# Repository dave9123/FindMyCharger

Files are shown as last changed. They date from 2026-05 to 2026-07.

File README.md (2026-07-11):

# FindMyCharger

<p align="center">
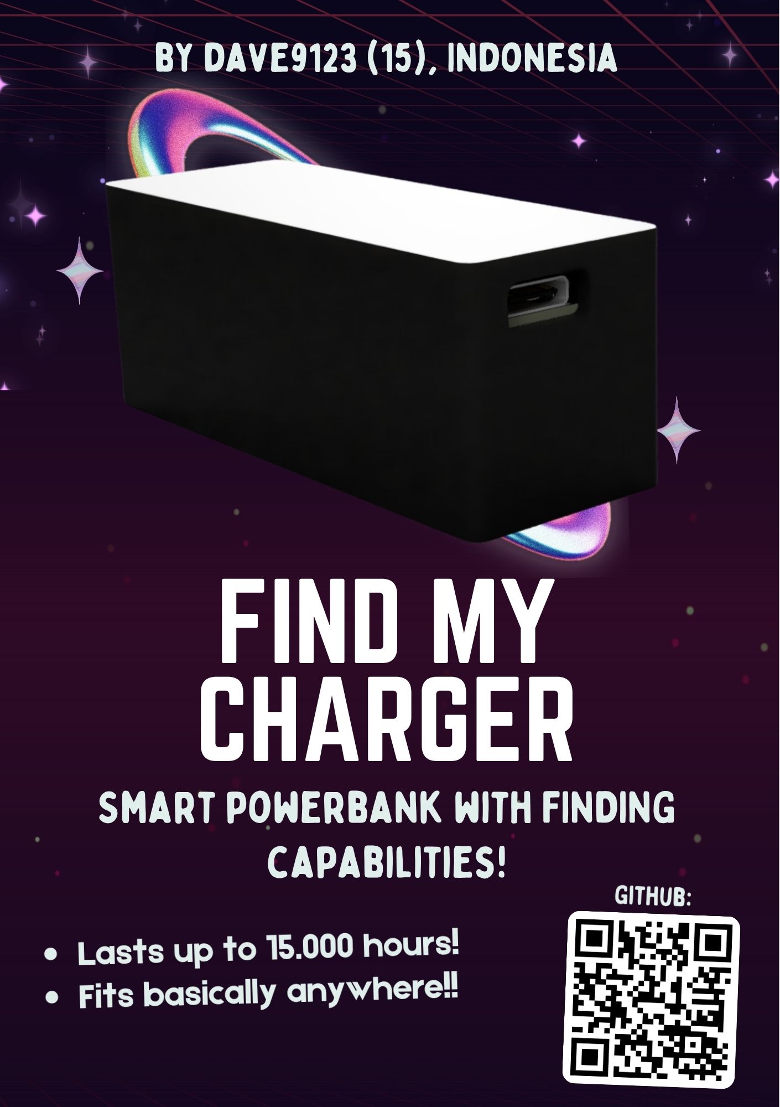
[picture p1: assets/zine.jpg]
	
	<br><a href="./zine.pdf">View Magazine</a> - <a href="#bom">View BOM</a>
</p>

FindMyCharger is a smart powerbank with finding capabilities so you don't have to worry where did you place your powerbank!

## Why?

I've been forgetting things a lot, also it can be part of aging (or ekhem ekhem sleep depreviation) which then causes people to lose their stuff. I don't hope for it, but there might be a chance that someone would steal your bag, and this just gives you a piece of mind!

## How it Works

IP5353 handles powerbank-like controls for charging and charging other devices, E104-BT5005A (based on nRF52805) transmits BLE packets which can be used with [Apple's FindMy](https://github.com/dchristl/macless-haystack) and/or [Google's Find Hub](https://github.com/leonboe1/GoogleFindMyTools).

## Build Instructions

You can either:
- PCBA
- Manual Solder 

Afterwards, you'll need:

1. Everything from [BOM](./BOM.md) (pick PCBA/detailed depending on your usecase)
2. SWD Debugging Interface
3. 4x Jumper Wires

(additional if manual solder)

4. Soldering Iron
5. Solder

Steps:
1. Print the PCB from [pcb/jlcpcb/production_files/GERBER-FindMyCharger.zip](./pcb/jlcpcb/production_files/GERBER-FindMyCharger.zip)
2. Solder the components based on [BOM](#BOM) or PCBA with [JLCPCB CPL](./pcb/jlcpcb/production_files/CPL-FindMyCharger.csv) and [JLCPCB BOM](./pcb/jlcpcb/production_files/BOM-FindMyCharger.csv)
3. 3D print the casing in [CAD folder](./cad/components/)
4. Place the battery on the bottom holder

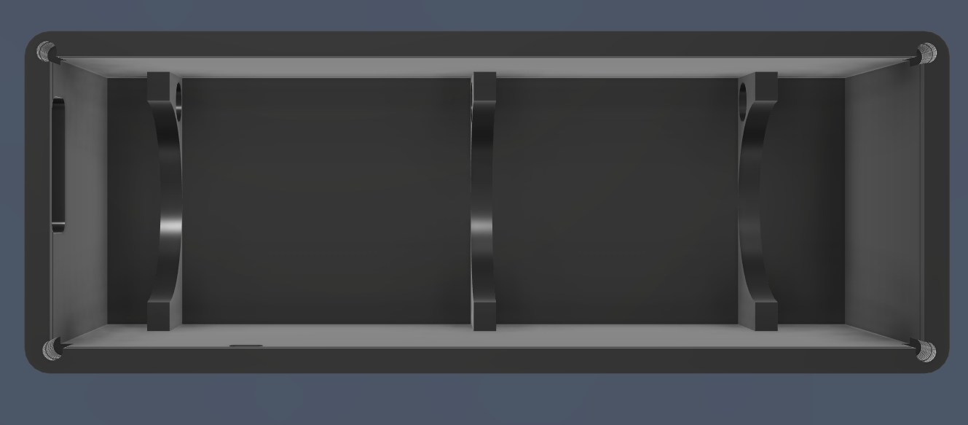
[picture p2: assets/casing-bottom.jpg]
Bottom Casing
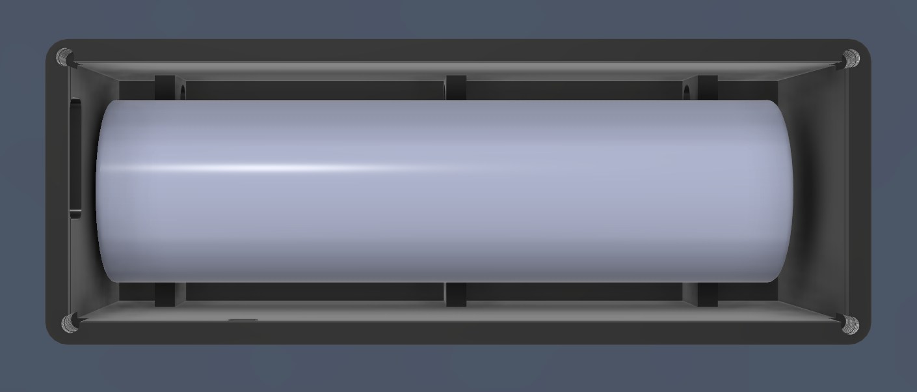
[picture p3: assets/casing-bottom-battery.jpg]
Bottom Casing with Battery
|  |  |
| :---: | :---: |

5. Solder battery with wires (to be soldered on the PCB)
6. Place the bottom holder dock

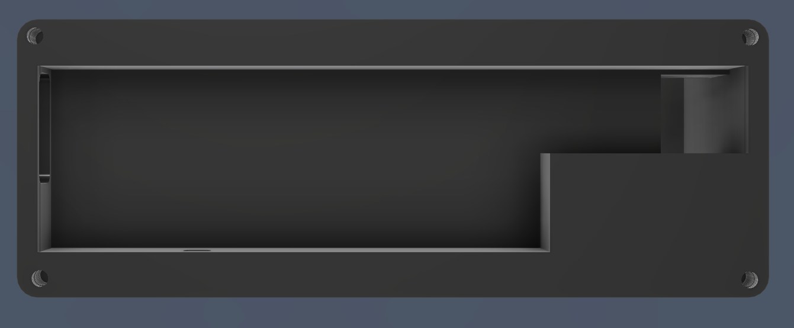
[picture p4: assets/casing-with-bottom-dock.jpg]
Casing with Bottom Holder Dock
| Bottom Casing with Battery |  |
| :---: | :---: |

7. Place and fit the PCB on the dock

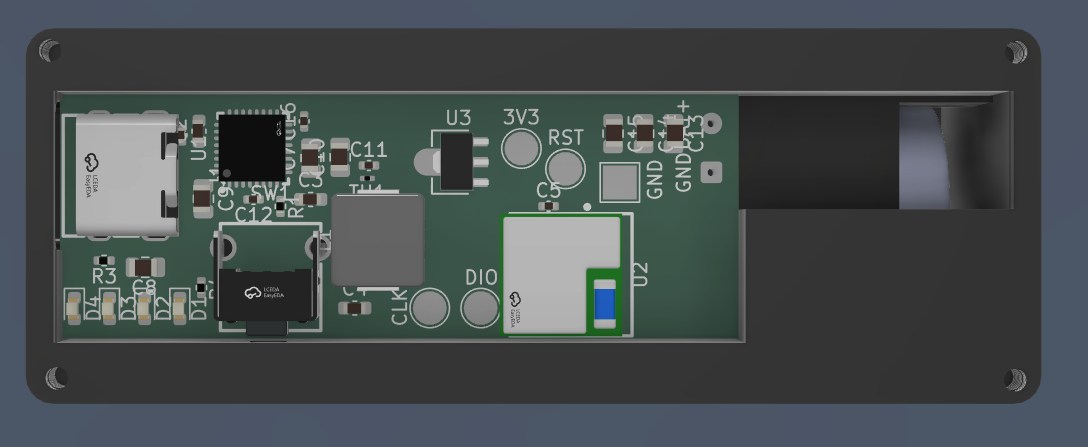
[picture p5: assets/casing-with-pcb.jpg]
Casing with PCB on the dock
| Casing with Bottom Holder Dock |  |
| :---: | :---: |

8. Build and flash the [firmware](#firmware) by connecting a SWD debugger to (SW)DIO, (SW)CLK, and GND
9. Place the top and screw it with M2x6

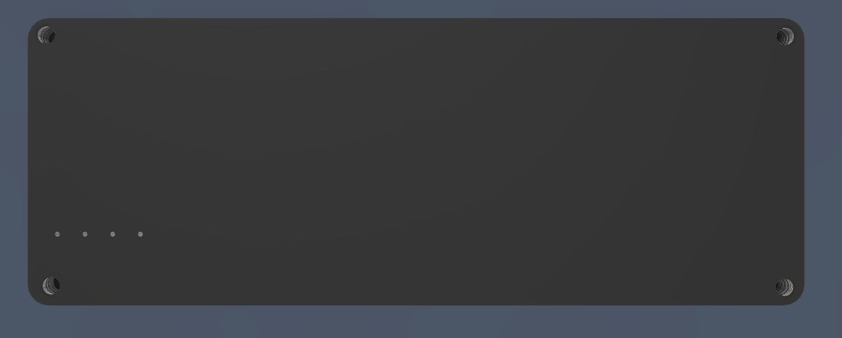
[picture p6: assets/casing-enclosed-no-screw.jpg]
Casing with Top
| Casing with PCB on the dock |  |
| --- | --- |

## Firmware

The firmware for FindMyCharger is using [Macless Haystack](https://github.com/dchristl/macless-haystack), a framework for custom FindMy network without having to own a Mac.

Macless Haystack is included in this repository as a submodule under [firmware/macless-haystack](../firmware/macless-haystack/)

### Prerequisites (guide below to install):

1. nRF Connect SDK
2. https://github.com/dchristl/macless-haystack repo or current (follow guide below)
3. Python 2/3 (with pip), download [here](https://www.python.org/downloads/)
4. Pip package ["cryptography"](http://pypi.org/project/cryptography) -- `pip install cryptography`
5. Visual Studio Code, download [here](https://code.visualstudio.com/)
6. CMake, download [here](https://cmake.org/download/) or `sudo apt install cmake`

 ### Clone repository along with submodules:

7. Install the ["nRF Connect for VS Code" VSCode Extension here](https://marketplace.visualstudio.com/items?itemName=nordic-semiconductor.nrf-connect)

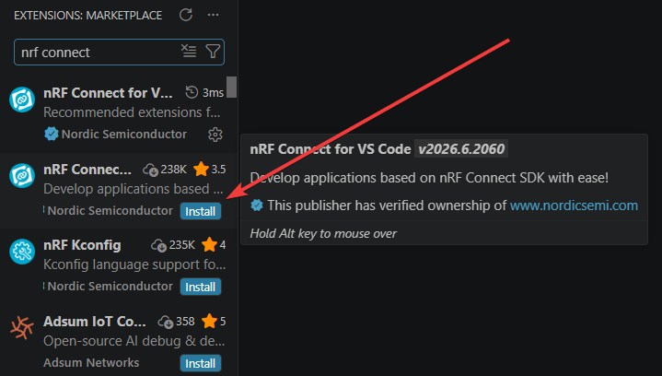
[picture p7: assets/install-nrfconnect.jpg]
Search for "nRF Connect for VS Code" and click Install


2. Open the nRF Connect extension on the left bar

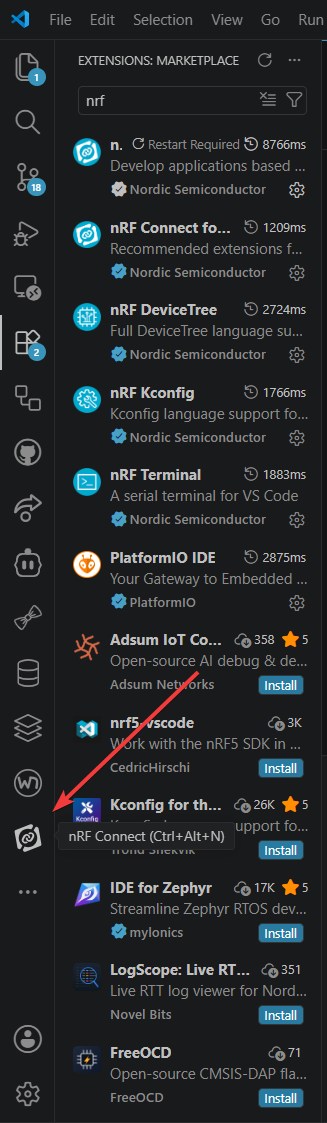
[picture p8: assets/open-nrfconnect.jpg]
Click on the chain with rectangles logo (nRF Connect extension)


3. Click on "Install SDK" and pick the latest version
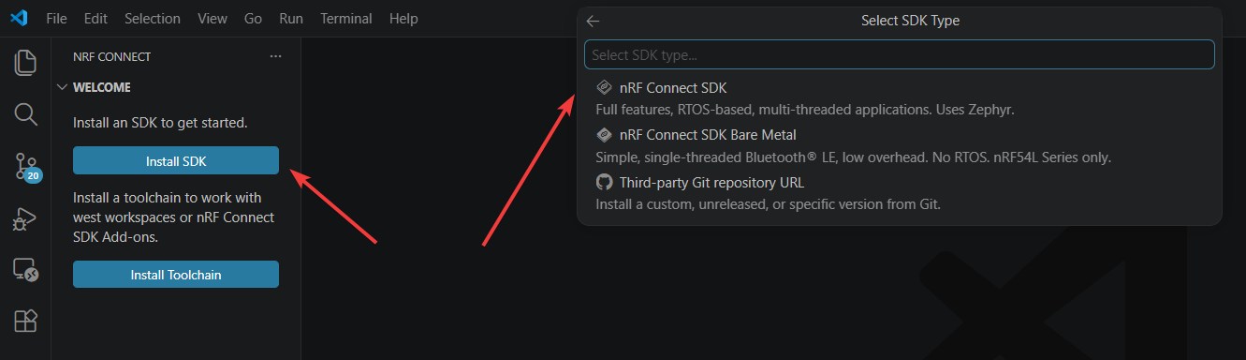
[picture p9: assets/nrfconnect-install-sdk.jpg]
Selecting "nRF Connect SDK" on SDK installation with nRF Connect for VS Code extension


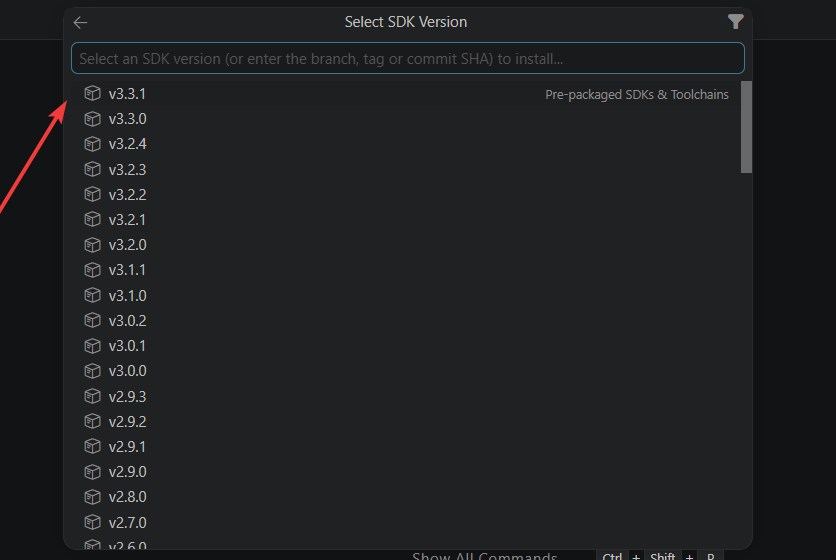
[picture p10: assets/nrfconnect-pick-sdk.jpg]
Picking the SDK version on nRF Connect

4. Click on "Install Toolchain" and pick the latest version

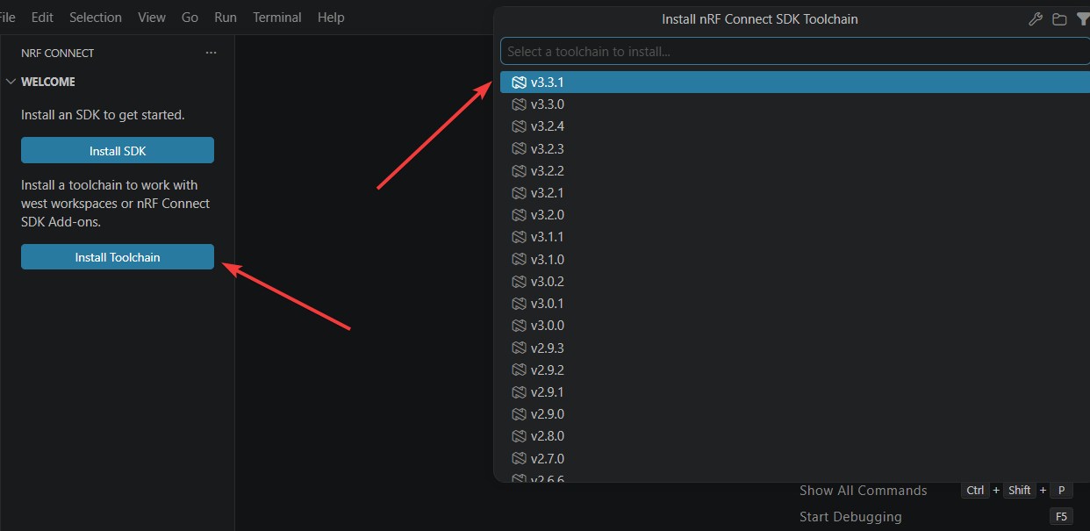
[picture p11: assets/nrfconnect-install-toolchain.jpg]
Clicking on "Install Toolchain" and picking the latest version


5. Wait for it to finish installing

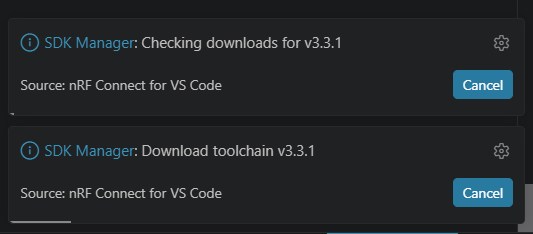
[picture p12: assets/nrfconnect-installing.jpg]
Installing progress notification


### Clone repository along with submodules

```
git clone --recurse-submodules https://github.com/dave9123/FindMyCharger

cd FindMyCharger/firmware/macless-haystack

git -C macless-haystack submodule update --init --remote --recursive
```

Then, you'll need to download the firmware (nrf52_firmware.bin) at Macless Haystack releases [here](https://github.com/dchristl/macless-haystack/releases) or build your own:
```
cd firmware/macless-haystack

py generate_keys.py # Note the output folder from the output "Output will be written to {OUTPUT_FOLDER}"

cd firmware/nrf5x

NRF_MODEL=nrf52 BOARD=BOARD_E104BT5032A make build

make patch
```

### Afterwards, update the finding public key

note: use Git Bash on Windows
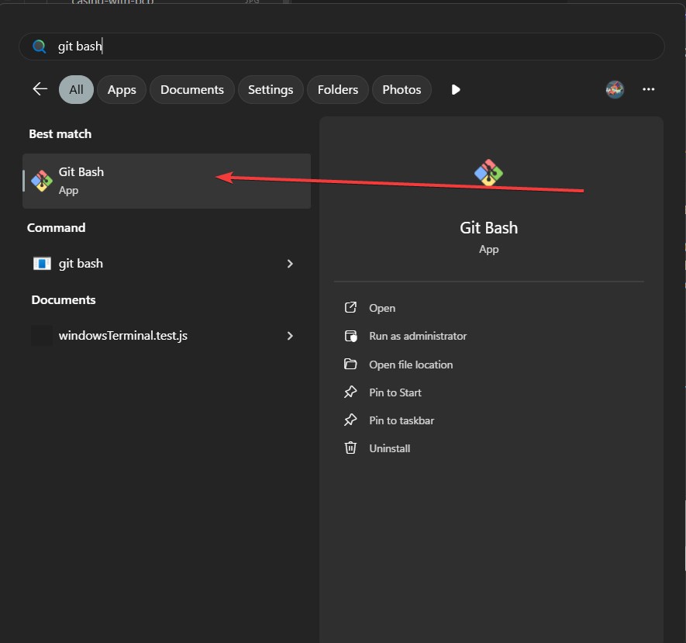
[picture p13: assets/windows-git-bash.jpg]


Replace "PREFIX_keyfile" with the path to your generated public key (stored in the ../../output folder)

```
export LC_CTYPE=C

xxd -p -c 100000 PREFIX_keyfile | xxd -r -p | dd of=nrf52_firmware.bin skip=1 bs=1 seek=$(grep -oba OFFLINEFINDINGPUBLICKEYHERE! nrf52_firmware.bin | cut -d ':' -f 1) conv=notrunc
```

### Patch and deploy firmware

```
openocd -f interface/stlink.cfg -c "transport select hla_swd" -f target/nrf52.cfg -c "init; halt; nrf5 mass_erase; program nrf52_firmware.bin verify; reset run; exit"
```

The complete guide on setting Macless Haystack can be found [here](https://github.com/dchristl/macless-haystackhttps://github.com/dchristl/macless-haystack)!

## Casing

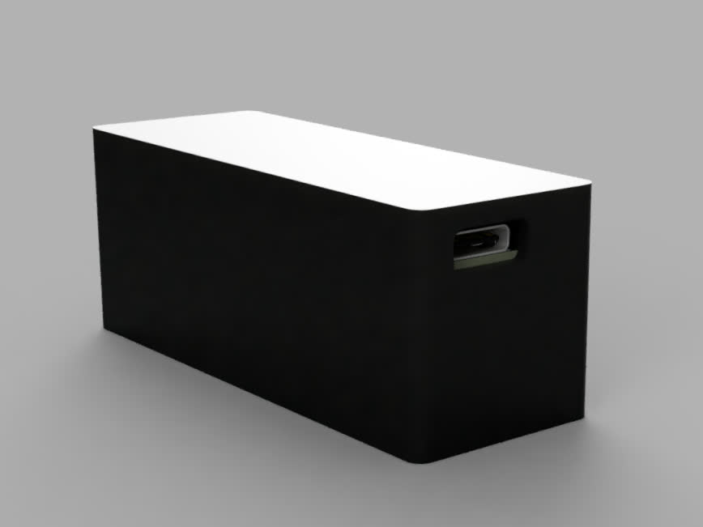
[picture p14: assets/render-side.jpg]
Side View
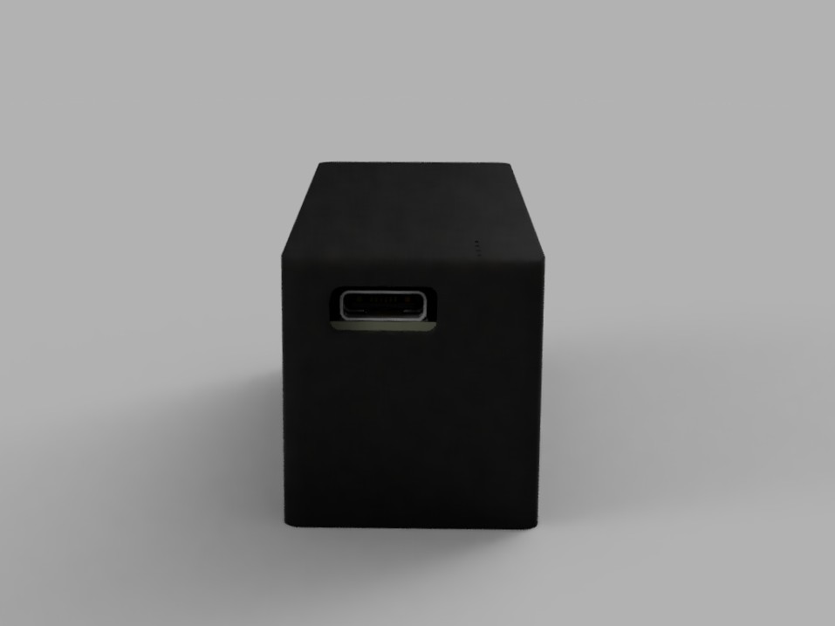
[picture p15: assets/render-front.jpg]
Front View
|  |  |
| :---: | :---: |

I'm honestly really proud of how it ends up, especially the sliding mechanism which makes everything easier to place

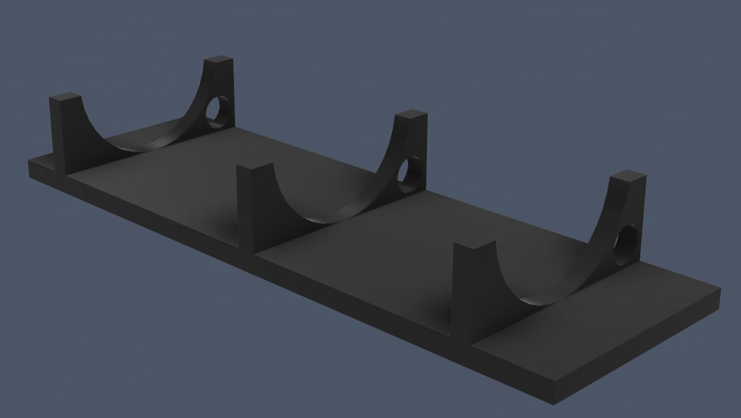
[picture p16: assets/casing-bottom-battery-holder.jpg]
Bottom Battery Holder
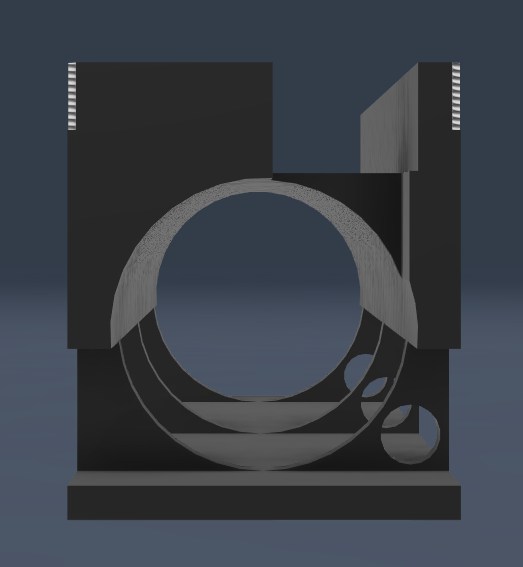
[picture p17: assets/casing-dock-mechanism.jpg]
Docking Mechanism
|  |  |
| :---: | :---: |

The holes on the side is for the cable to passthrough either the GND or positive side of the battery to be soldered onto the PCB

## Schematics

Detailed components list used can be found in the [BOM section](#bom)

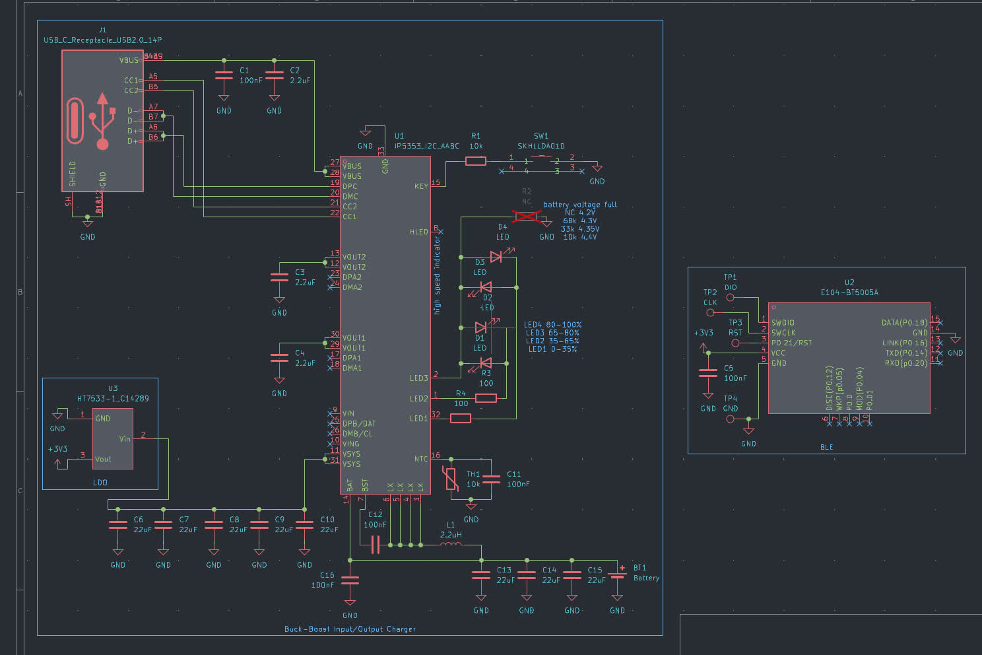
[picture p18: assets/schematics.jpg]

[View PDF](./assets/schematics.pdf)

## PCB

| Design | Rendered |
| :---: | :---: |
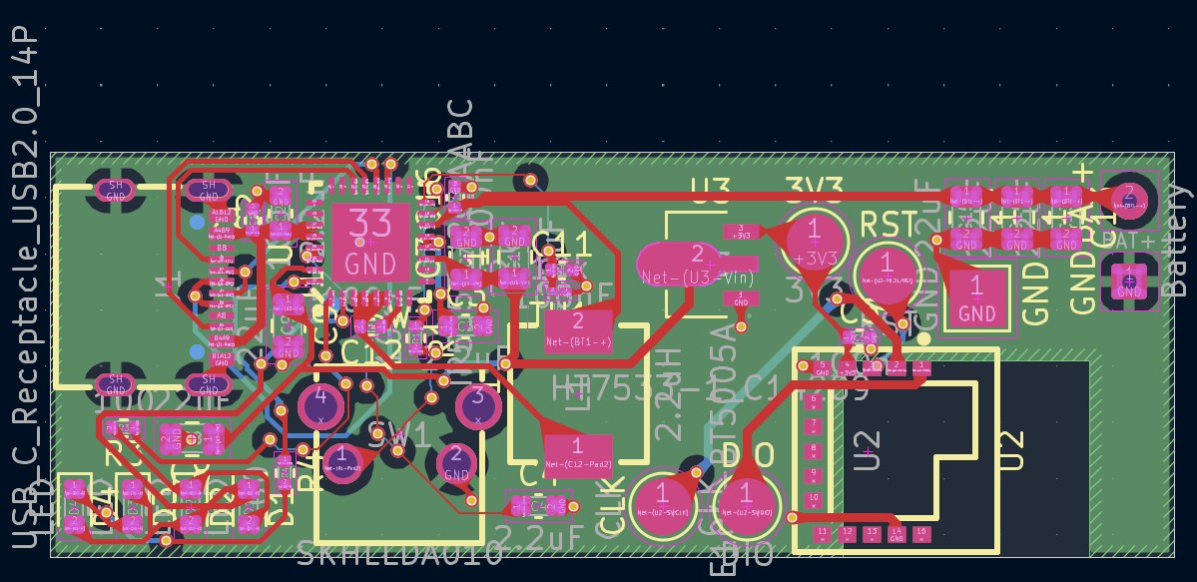
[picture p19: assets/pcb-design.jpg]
PCB Layout Design
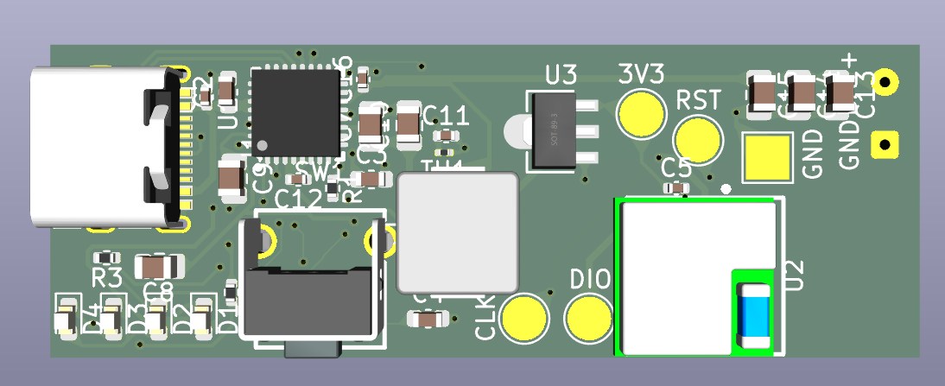
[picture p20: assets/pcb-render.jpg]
Rendered PCB
|  |  |

[View PDF](./assets/pcb.pdf)

Footprints used:
1. Battery Solder Pad - `Connector_Wire:SolderWire-0.1sqmm_1x02_P3.6mm_D0.4mm_OD1mm`
2. Capacitor 100nF - `Capacitor_SMD:C_0402_1005Metric`
3. Capacitor 2.2uF - `Capacitor_SMD:C_0603_1608Metric`
4. Capacitor 22uF - `Capacitor_SMD:C_0805_2012Metric`
5. LED `LED_SMD:LED_0603_1608Metric`
6. USB C Receptacle - `footprints:USB-C-SMD_TYPE-C16PIN` (imported from EasyEDA, included under `pcb/libraries/footprints.pretty)
7. Inductor 2.2uH - `footprints:IND-SMD_L6.0-W6.0_CHILISIN_HPPC06030` (imported from EasyEDA, included under `pcb/libraries/footprints.pretty`)
8. Resistor 10kΩ - `Resistor_SMD:R_0402_1005Metric`
9. Resistor 100Ω - `Resistor_SMD:R_0402_1005Metric`
10. 90deg Tactile Button - `footprints:KEY-TH_SKHLLDA010` (imported from EasyEDA, included under `pcb/libraries/footprints.pretty`)
11. Test Points - `TestPoint:TestPoint_Pad_D2.5mm`
12. IP5353 (charging) - `footprints:QFN-32_L5.0-W5.0-P0.50-TL-EP3.5` (imported from EasyEDA, included under `pcb/libraries/footprints.pretty`)
13. E104-BT5005A (BLE) - `footprints:BULETM-SMD_E104-BT5005A` (imported from EasyEDA, included under `pcb/libraries/footprints.pretty`)
14. 3.3V Voltage Regulator - `footprints:SOT-89-3_L4.5-W2.5-P1.50-LS4.2-BR` (imported from EasyEDA, included under `pcb/libraries/footprints.pretty`)

## BOM

### PCBA

| Item | Quantity | Total Cost | Order |
| --- | --- | --- | --- |
| M2x6 Screw | 4 | Rp5.000<br>~$0.28  | https://www.tokopedia.com/archive-lapaktukang/10pcs-baut-hitam-m2-m2x3-m2x4-m2x5-m2x6-m2x7-m2x8-m2x10-1731486102402008940 |
| 18650 Li-on Battery | 1 | Rp27.500<br>~$1.54 | https://www.tokopedia.com/nayfastore/baterai-isi-ulang-baterai-tipe-lithium-ion-18650-butontop-3000mah-3-7v-isi-2-pcs-1731453786169640483 |
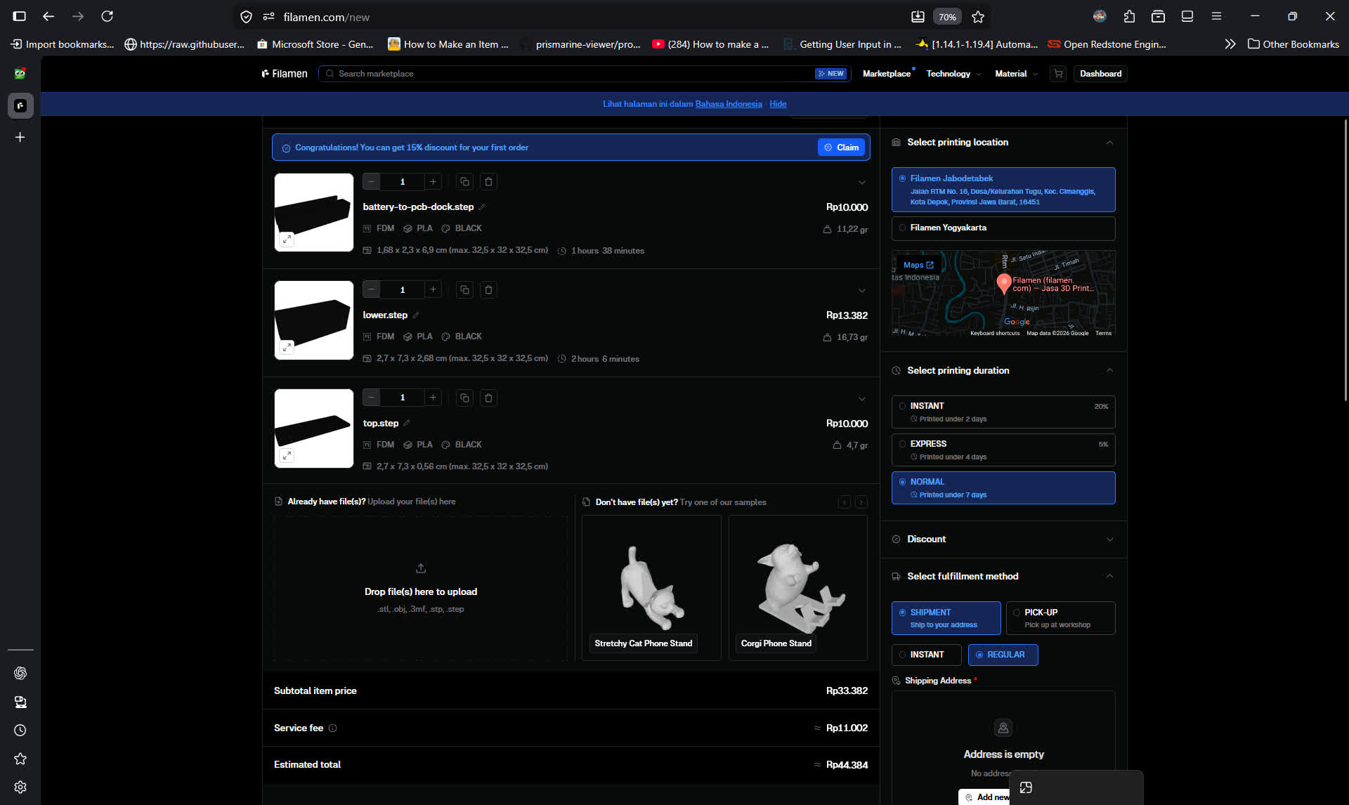
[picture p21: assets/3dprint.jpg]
| Casing 3D Print | 1 | Rp44.384<br>~$2.49 |  |
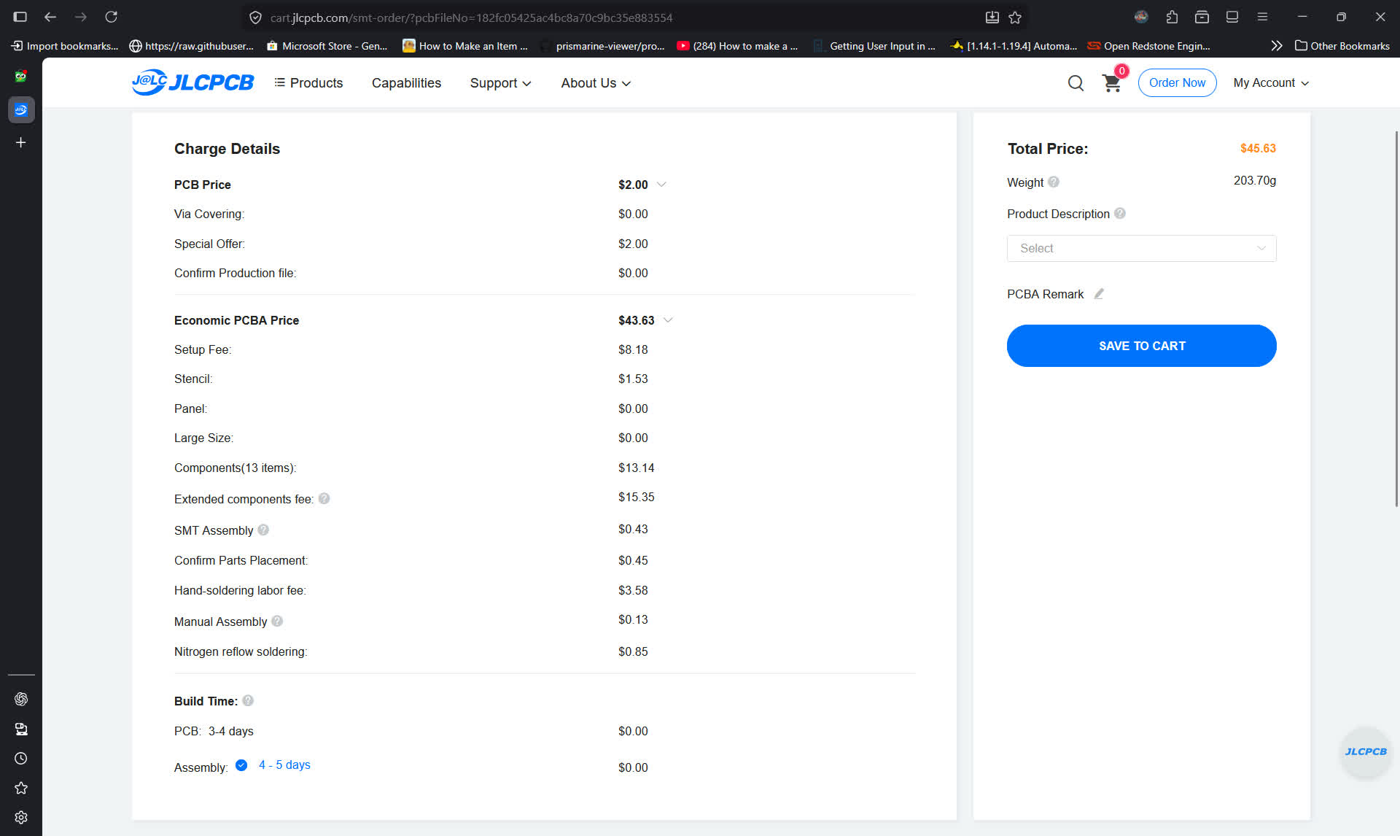
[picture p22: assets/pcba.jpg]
| PCBA | 1 | $45.63 |  |
| Wire | 2 | Rp4.000<br>~$0.22  | https://www.tokopedia.com/cncstorebandung/kabel-tunggal-mini-wire-single-core-tinned-cu-permeter-hitam-merah-hijau-kuning-putih-0-6mm-hitam-27149 |
| | | | |
| Total | | $48.4 | |

### Detailed

| Item | Quantity | Total Cost | Order |
| --- | --- | --- | --- |
| M2x6 Screw | 4 | Rp5.000<br>~$0.28  | https://www.tokopedia.com/archive-lapaktukang/10pcs-baut-hitam-m2-m2x3-m2x4-m2x5-m2x6-m2x7-m2x8-m2x10-1731486102402008940 |
| 18650 Li-on Battery | 1 | Rp27.500<br>~$1.54 | https://www.tokopedia.com/nayfastore/baterai-isi-ulang-baterai-tipe-lithium-ion-18650-butontop-3000mah-3-7v-isi-2-pcs-1731453786169640483 |
| Casing 3D Print | 1 | Rp44.384<br>~$2.49 |  |
| Wire | 2 | Rp4.000<br>~$0.22  | https://www.tokopedia.com/cncstorebandung/kabel-tunggal-mini-wire-single-core-tinned-cu-permeter-hitam-merah-hijau-kuning-putih-0-6mm-hitam-27149 |
| Resistor 100Ω 0402 | 2 | $0.002 | C25076 (JLCPCB) |
| Capacitor 100nF 0402 | 5 | $0.04 | C307331 (JLCPCB) |
| Resistor 10k 0402 | 1 | $0.015 | C25744 (JLCPCB) |
| Thermistor 10k 3380K 0402 | 1 | $0.008 | C29553871 (JLCPCB) |
| Capacitor 2.2uF 0603 | 3 | $0.027 | C23630 (JLCPCB) |
| Inductor 2.2uH SMD 6.0x6.0mm | 1 | $0.24 | C285900 (JLCPCB) |
| USB C Receptacle 16P | 1 | $0.065 | C393939 (JLCPCB) |
| Capacitor 22uF 0805 | 7 | $0.665 | C45783 (JLCPCB) |
| LED White 0603 | 4 | $0.048 | C2290 (JLCPCB) |
| 90deg Tactile Button SKHLLDA010 | 1 | $0.239 | C125032 (JLCPCB) |
| Bluetooth Module E104-BT5005A | 1 | $3.67 | C2874127 (JLCPCB) |
| 3.3V LDO HT7533 | 1 | $0.125 | C14289 (JLCPCB) |
| Charging Module IP5353 | 1 | $0.999 | C46550234 (JLCPCB) |
| 4-layer PCB | 1 | $2.1 | JLCPCB |
| | | | |
| Total | | $12.55 | |
note: JLCPCB components are for PCBA only and total cost doesn't factor extended ($3) cost nor PCBA fees

note 2: price does not include shipping, taxes, customs (import) nor Minimum Order Quantity (MOQ)

*price as of 27/06/2026 03:22 GMT+7*

## Credits

Software used:
- [KiCad](https://kicad.org/)
- [Autodesk Fusion](https://www.autodesk.com/education/edu-software/fusion)

- 18650 Battery 3D model: https://grabcad.com/library/cell-18650-1
- Macless Haystack: https://github.com/dchristl/macless-haystack

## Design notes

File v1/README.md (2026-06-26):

# FindMyCharger

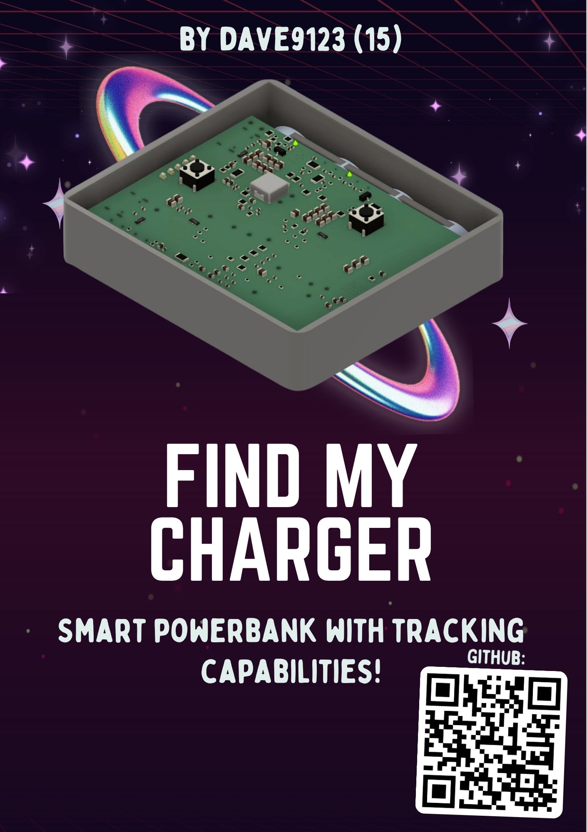
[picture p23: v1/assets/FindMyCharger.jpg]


[Bill of Material](./pcb/jlcpcb/production_files/BOM-FindMyCharger.csv)

A smart powerbank with locating capabilities through Apple FindMy network

- Low power at 10mA BLE transmission at +8dBm
- Charging input/output up to 60W
- 5 LED battery indicator

## Why did I make this?

There were 2 consecutive bicycle robbery that happened near where I live which got me curious, where do they place them at? With this, no SIM card nor GPS needed (which saves energy and mobile credits)!

## Firmware

I'm using [Macless Haystack](https://github.com/dchristl/macless-haystack), a framework for custom FindMy network without having to own a mac

Macless Haystack is included in this repository as a submodule under [firmware/macless-haystack](../firmware/macless-haystack/)

## Screenshots

### Casing

*18650 battery model from https://grabcad.com/library/cell-18650-1

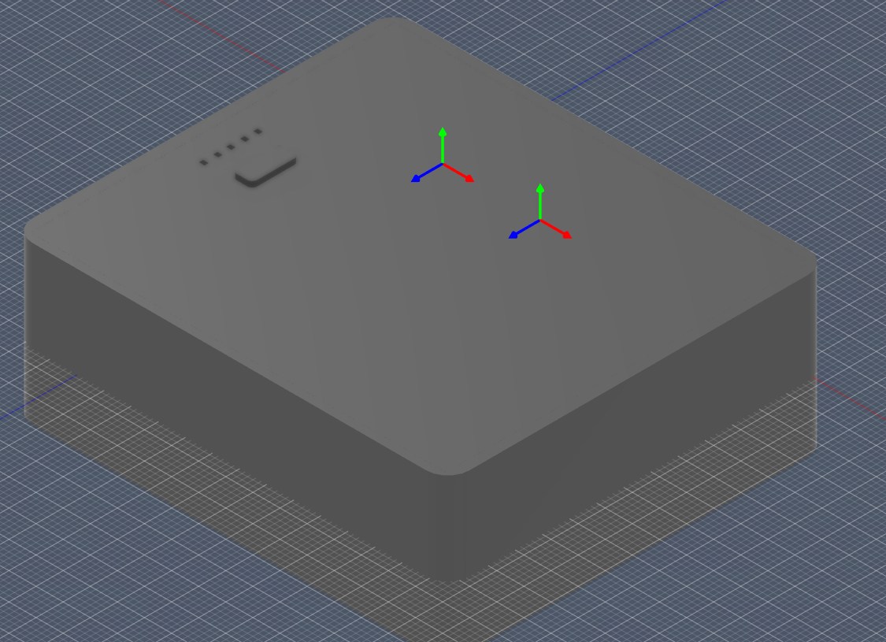
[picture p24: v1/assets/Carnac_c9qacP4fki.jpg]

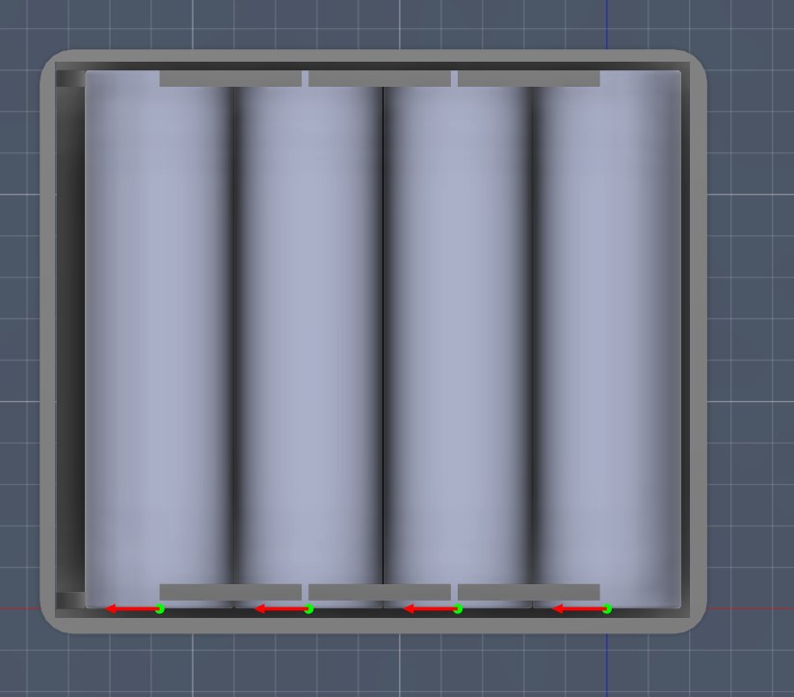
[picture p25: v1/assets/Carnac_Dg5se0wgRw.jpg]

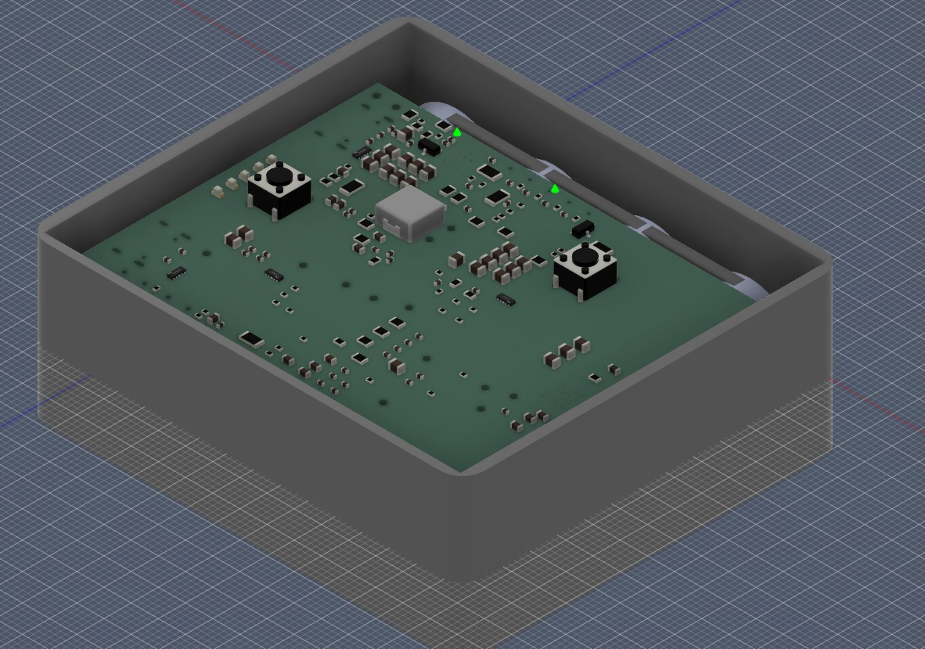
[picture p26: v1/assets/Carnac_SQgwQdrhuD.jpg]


### Schematics

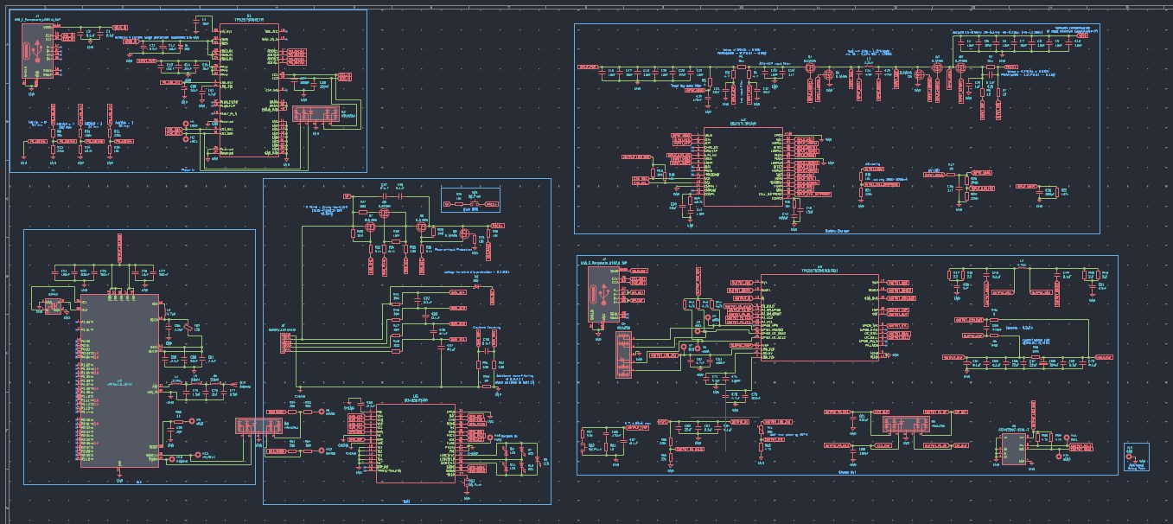
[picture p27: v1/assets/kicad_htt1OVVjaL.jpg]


### PCB

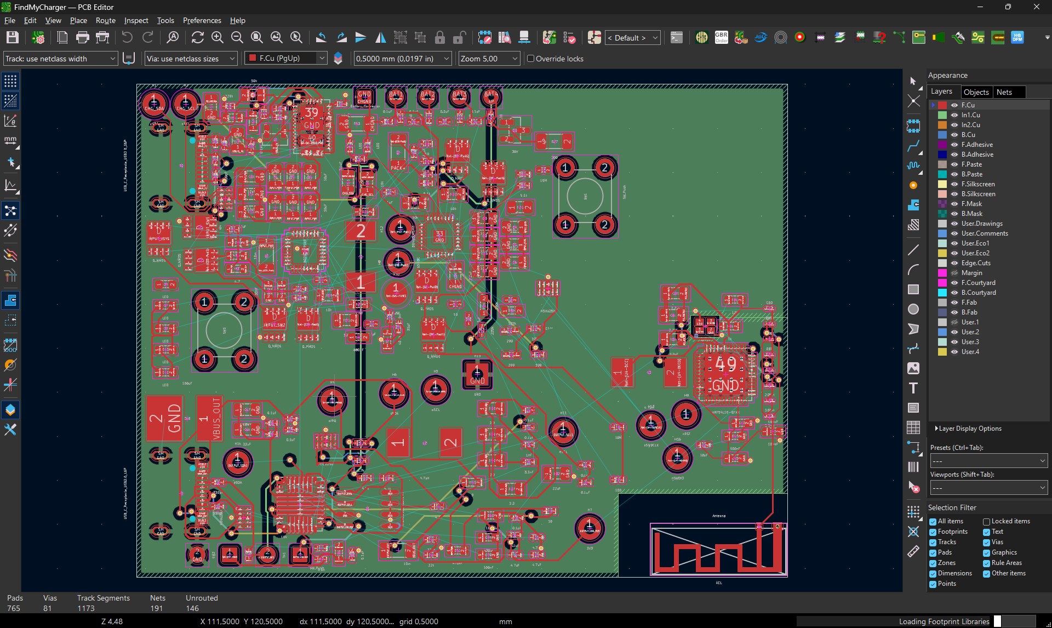
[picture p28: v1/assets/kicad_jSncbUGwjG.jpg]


## I want one!!

You'll need to:
1. Order the PCB (or get PCBA assembly), please check [docs/calculations.md](./docs/calculations.md) for components requirements and [pcb/gerber_to_order](./v1/pcb/gerber_to_order/) for gerber
2. Print bottom, button, and upper which can be found at [cad](./v1/cad)
3. Get additional components/parts, list [here](#additional-components) and solder them
4. Place components and glue casing

## Addiitonal components

- 2x Tactile Button 6mm
- 4x Li-on 18650 battery
- Nickel strip (for better conductivity)

## Todo

- Include battery level transmission
- Smaller footprint
- Ultra Wide Band (UWB) for precise finding
- Support PD2.0 / PD3.1 / PPS, QC2/3/4/5, FCP / SCP / SFCP, AFC, MTK PE, Apple / BC1.2, UFCS (new universal Chinese standard)
- Support multiple controls (press, press & hold) on button
- Integrate both Macless Haystack and [Google FindMy](https://github.com/leonboe1/GoogleFindMyTools)) into one

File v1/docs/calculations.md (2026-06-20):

*value rounded up for obvious safety reasons
## calc tps25762-q1

### output caps - 9.2.2.6

```
Icout(rms) = 3A*sqrt(21V/12V - 1) = 2.59A
Icout(rms) = 3A*sqrt(21V/16.8V - 1) = 1.5A

Icout(rms) = 3.25A*sqrt(20V/12V - 1) = 2.65A
Icout(rms) = 3.25A*sqrt(20V/16.8V - 1) = 1.42A

Vripple(Cout) = 3.25A*(1 - 12V/20V) / (144uF*10^-6 * 400kHz*10^3) ~= 0.0225V = 22.5mV (that's if MLCC don't decide to lower their capacitance)
```

### input caps - 9.2.2.7

```
D = Vout-Vin/Vout = 21-12/21 ~= 0.43
> from https://www.everythingpe.com/calculators/duty-cycle-calculator

Icin(rms) = 3.25A * sqrt(0.43*(1-0.43)) ~= 1.61A
```
### thermal foldback
default config w R1 10k thermistor 3950 NTC - R2 3.3k

|Phase|Enter Threshold (V)|NTC Enter (Ohm)|Temp Enter (°C)|Exit Threshold (V)|NTC Exit (Ohm)|Temp Exit (°C)|Max Power (%)|
|:-:|:-:|:-:|:-:|:-:|:-:|:-:|:-:|
|1|2.044 V|2.892 kΩ|56.88°C|1.988 V|3.101 kΩ|55.10°C|60%|
|2|2.100 V|2.686 kΩ|58.75°C|2.044 V|2.892 kΩ|56.88°C|30%|
|3|2.142 V|2.546 kΩ|60.08°C|2.086 V|2.731 kΩ|58.33°C|0%|

### inductor
```
vin -> 12-16.8V
vout -> 5-21V
iout -> 3-3.25A
fsw -> 400kHz

Dbuck = 5V/(16.8V*0.9) = 0.33
Il_buck(max) = (16.8V-5V)*0.33/(400KHz*(10^3) * 4.7uH*(10^-6)) = 2.07A
Isw_buck(max) = 2.07/2 + 3.25 = 4.29A
Imaxout(buck) = 6.2A - 2.07A/2 = 5.17A

Dboost = 1-(12*0.95)/21 = 0.46
Il_boost(max) = 12V*0.46/(400KHz*(10^3) * 4.7uH*(10^-6)) = 2.94A
Isw_boost(max) = 2.94A/2 + 3.25A/(1-0.45) = 7.38A
Imaxout(boost) = (8.2A-2.94A/2) * (1-0.46) = 3.63A
```
switching max is 7.38A, so pick higher
### LDO
external current limit 25 mA

nRF54 TX 10 mA
EEPROM 5 mA max (?, max dc output current @ absolute maximum rating)
pull up resistors, TODO: calculate power used

### i2c pull up

![[Pasted image 20260615203838.png]]

capacitive load seems to be worst case scenario, TODO: calculate capacitive load
```
-> min = (3.3V-0.4V) / (3mA*10^-3) = 966.666667

standard mode (max)
 -> max = 1000ns*10^-9 / (0.8473 * 400pF*10^-12) = 2950.54880208

fast mode (max)
 -> max 300ns*10^-9 / (0.8473 * 400pF*10^-12) = 885.16464062

fast mode plus (max)
 -> max = 120ns*10^-9 / (0.8473 * 550pF*10^-12) = 257.50244091
```
## calc bq25713
### mosfet
```
duty cycle (buck) -> D = Vout/Vin
= 16.8V/20V = **0.84**
= 12V/20V = 0.6

duty cycle (boost) -> D = 1 - Vin/Vout
= 1 - 5V/16.8V = 0.70
= 1 - 5V/12V = 0.42

Ptop = 0.84 * 3.2A^2 * Rds(on) * 1/2 * 21V * (ton + toff) * 800kHz*10^3

Pbottom = (1-0.42) * 3.2A^2 * Rds(on) = 5.939 * Rds(on)
```

### inductor - 10.2.2.2
```
D = duty cycle

Dbuck = Vout/Vin
= (12/20) = 0.6

Iripple_buck = Vin * D * (1 - D) / (fs * L)
= 20V * 0.6 * (1-0.6) / (800kHz*(10^3) * 2.2uH*(10^-6))
= 2.73A (peak buck)

Dboost = 1 - (Vin/Vbat)
= 1 - (5V/16.8V) = 1 - 0.2976.. = 0.71

Iripple_boost = (VIN * Dboost) / (fs * L)
= (5V * 0.71) / ((800kHz*(10^3) * 2.2uH*(10^-6))
  = 2.02A (peak boost)

Isat >= Ichg + 1/2*Iripple
  >= (60W/12V) + 1/2*2.73A
  >= 6.37A
```
inductor ripple range 20 – 40% as trade-off between size and efficiency

### input capacitor - 10.2.2.3
*duty cycle rounded down as worst case RMS seems to be half
> Input capacitor should have enough ripple current rating to absorb input switching ripple current. The **worst case RMS ripple current is half of the charging current** (plus system current there is any system load) when duty cycle is 0.5 in buck mode

*referencing duty cycle buck & boost values from inductor calc, 10.2.2.2

buck
Icin = 3A * sqrt(0.83*(1-0.83)) = 1.13A

boost
Icin = 3A * sqrt(0.70*(1-0.70)) = 1.38A

### power mosfet
gate drive -> 6V
input -> 19-20V -> derating +50% >= 30V

D = Vout/Vin
  = 16.8V/5V = 3.36
  = 16.8V/20V = 0.84

Qsw = Qgd + 1/2*Qgs

ton = 

toff = 

Ion = (6-)

Ioff = 

Ptop = 3.36 * (3A)^2 * Rds(on) + 1/2 * 5 * 3 * ()

MOSFET plateau voltage (Vplt) -> basically gate needs more voltage than threshold because of miller effect (when between in&out amplifier, Vout > Vin)
https://electronics.stackexchange.com/questions/392956/what-do-we-mean-by-gate-plateau-voltage
https://electronics.stackexchange.com/questions/141298/what-happpens-to-the-vgs-in-the-miller-plateau-region-during-mosfet-turn-on
ok now how am I supposed to calc Vplt, it's needed for figure-of-merit (FOM) calc

> max current non-sync -> 0.25A@10mΩ curent sensing or 0.5A if batt < 2.5V
> minimum duty cycle happens at lowest battery voltage
does this mean that less duty cycle = worst case scenario?

| Mode | Buck | Buck-Boost | Boost |
| :--: | :---: | :---: | :---: |
|  Q1  | Switching | Switching  | ON |
|  Q2  | Switching | Switching  | OFF |
|  Q3  | OFF | Switching  | Switching |
|  Q4  | ON | Switching  | Switching |
### battery cells
cell_batpresz at 8.5 BQ25713 "ANALOG INPUT (CELL_BATPRESZ)" 4S 6*300000/(100000+300000) = 4.5V (75%)
    - on 10% tolerance up to lowest 6 * 270000/(110000+270000) = 4.26V (71%)
    - on 15% tolerance up to lowest 6 * 255000/(115000+255000) = 4.13V (68.8%)

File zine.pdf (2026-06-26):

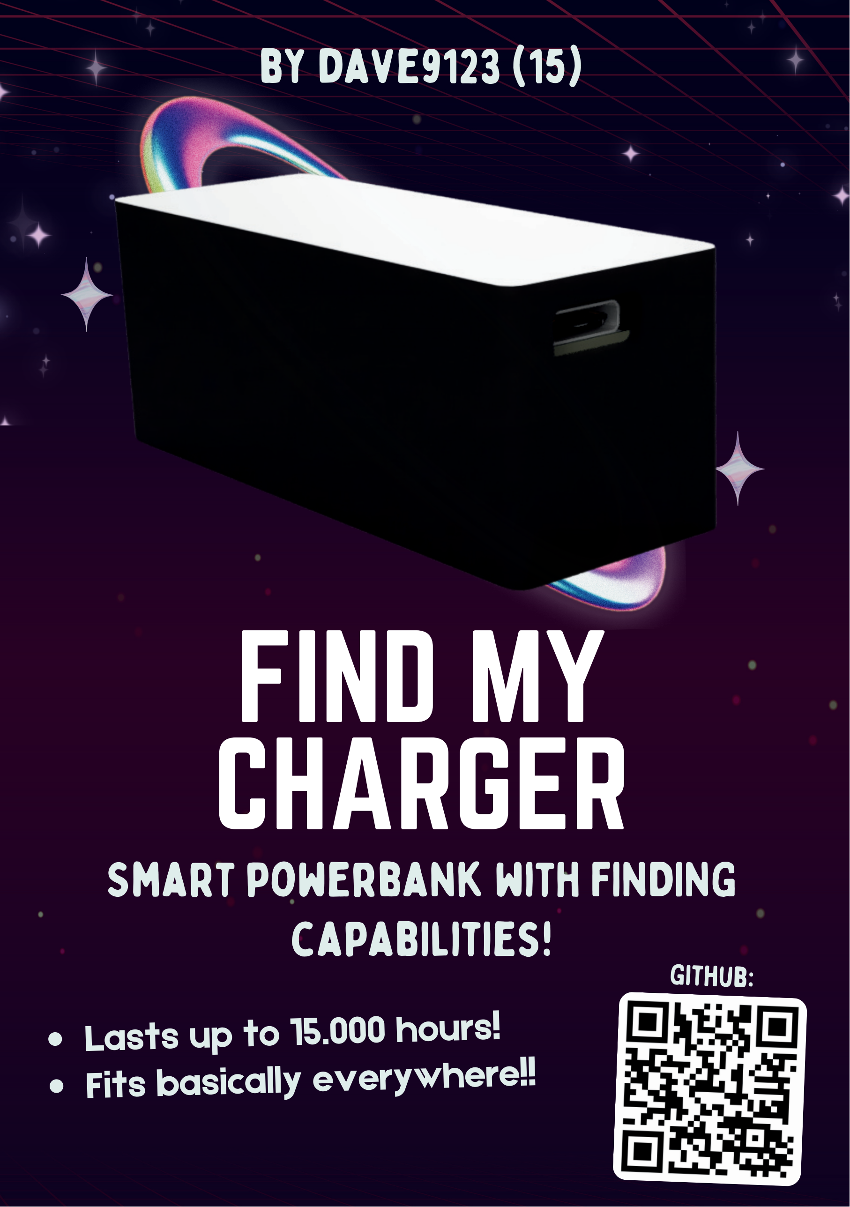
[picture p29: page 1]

# FIND MY CHARGER

Smart powerbank with FINDING capabilities!
Github:

by dave9123 (15)

Lasts up to 15.000 hours!
Fits basically everywhere!!

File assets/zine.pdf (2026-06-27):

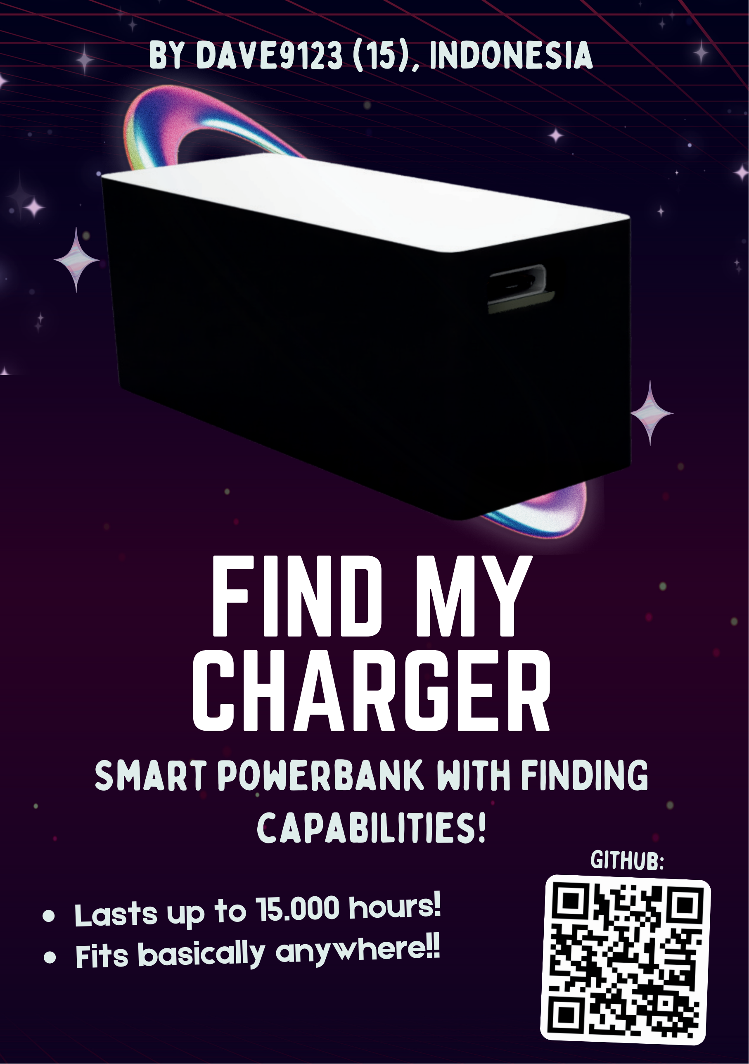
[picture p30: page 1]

# FIND MY CHARGER

### Smart powerbank with FINDING capabilities!

Github:

by dave9123 (15), Indonesia

Lasts up to 15.000 hours!
Fits basically anywhere!!

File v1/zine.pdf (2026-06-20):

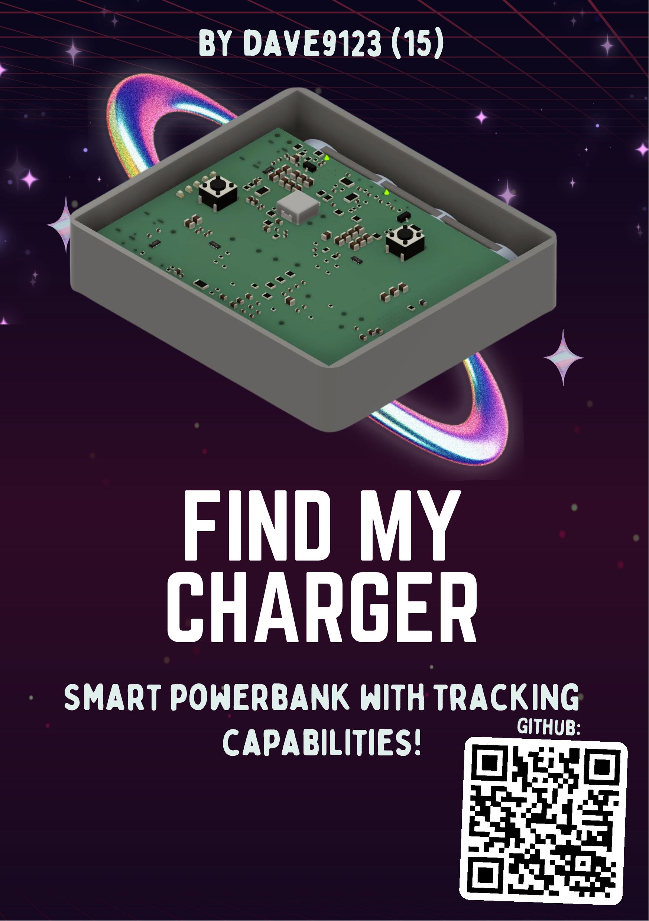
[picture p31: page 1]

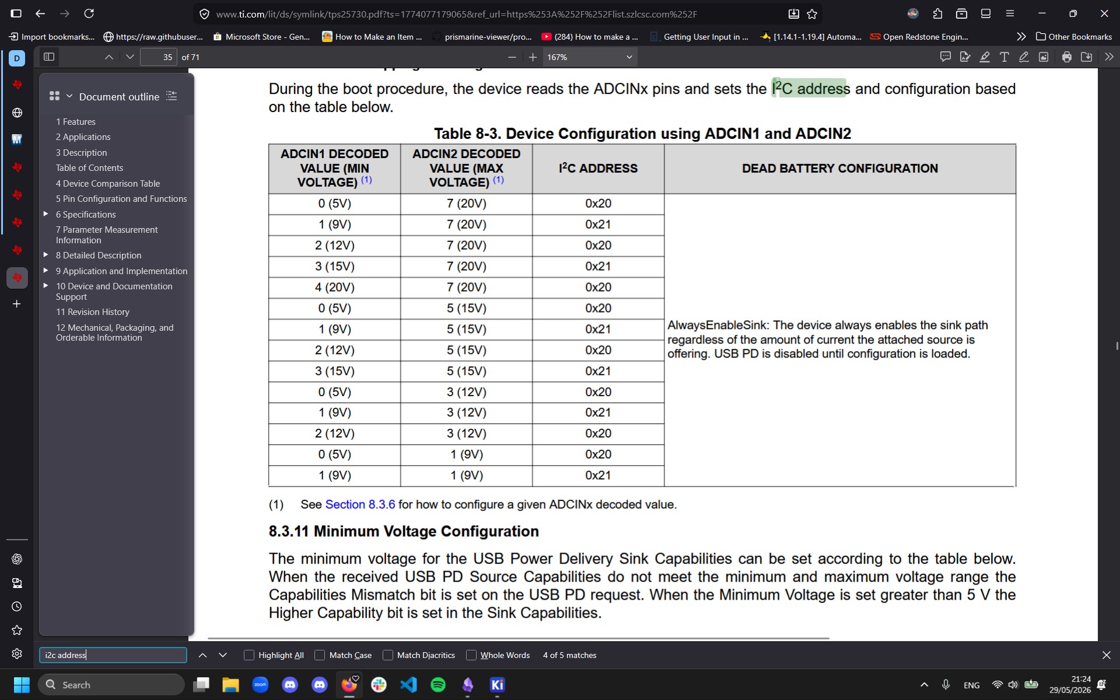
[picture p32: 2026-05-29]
v1/assets/firefox_of7rFwYYZ2.jpg

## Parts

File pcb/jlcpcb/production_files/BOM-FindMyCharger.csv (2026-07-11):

Comment | Designator | Footprint | LCSC | Quantity
100 | R3,R4 | R_0402_1005Metric | C25076 | 2
100nF | C1,C11,C12,C16,C5 | C_0402_1005Metric | C307331 | 5
10k | R1 | R_0402_1005Metric | C25744 | 1
10k | TH1 | R_0402_1005Metric | C41417281 | 1
2.2uF | C2,C3,C4 | C_0603_1608Metric | C23630 | 3
2.2uH | L1 | IND-SMD_L6.0-W6.0_CHILISIN_HPPC06030 | C285900 | 1
22uF | C10,C13,C14,C15,C6,C7,C8,C9 | C_0805_2012Metric | C45783 | 8
E104-BT5005A | U2 | BULETM-SMD_E104-BT5005A | C2874127 | 1
HT7533-1_C14289 | U3 | SOT-89-3_L4.5-W2.5-P1.50-LS4.2-BR | C14289 | 1
IP5353_I2C_AABC | U1 | QFN-32_L5.0-W5.0-P0.50-TL-EP3.5 | C46550234 | 1
LED | D1,D2,D3,D4 | LED_0603_1608Metric | C2290 | 4
SKHLLDA010 | SW1 | KEY-TH_SKHLLDA010 | C125032 | 1
USB_C_Receptacle_USB2.0_14P | J1 | USB-C-SMD_TYPE-C16PIN | C393939 | 1

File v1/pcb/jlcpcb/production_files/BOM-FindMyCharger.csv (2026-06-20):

Comment | Designator | Footprint | LCSC | Quantity
0 | R46 | R_0603_1608Metric | C21189 | 1
0.1uF | C11,C2,C26,C3,C37,C38,C48,C49,C52,C53,C56,C57,C58,C64,C65,C69,C70,C83,C84,C87 | C_0402_1005Metric | C307331 | 20
0.3pF | C77 | C_0201_0603Metric | C5448799 | 1
1 | R5 | R_0402_1005Metric | C25086 | 1
1.5pF | C75 | C_0201_0603Metric | C1552 | 1
1.8nF | C41 | C_0402_1005Metric | C696873 | 1
10 | R17,R48,R6,R61,R7 | R_0402_1005Metric | C25077 | 5
100 | R35,R41,R45,R47,R49,R51,R52,R55,R64 | R_0402_1005Metric | C25076 | 9
100nF | C43,C44,C45,C47,C63,C74,C79 | C_0603_1608Metric | C14663 | 7
100uF | C68 | CAP-SMD_L7.3-W6.1_TCN4227M025R0100 | C2158793 | 1
10M | R28,R29,R32 | R_0402_1005Metric | C52209954 | 3
10k | R15,R16,R18,R19,R25,R26,R30,R31,R9 | R_0805_2012Metric | C17414 | 9
10m | R1,R2,R50 | R_1206_3216Metric | C105362 | 3
10nF | C22,C60 | C_0402_1005Metric | C15195 | 2
10uF | C1,C30,C46 | C_0402_1005Metric | C15525 | 3
10uF | C10,C12,C15,C16,C17,C18,C19,C20,C21,C4,C5,C6,C7,C8,C9 | C_0805_2012Metric | C440198 | 15
120 | FB1 | L_0603_1608Metric | C14709 | 1
137k | R22 | R_0603_1608Metric | C321717 | 1
15pF | C40 | C_0402_1005Metric | C1548 | 1
160k | R10 | R_0603_1608Metric | C22813 | 1
1k | R56 | R_0603_1608Metric | C11702 | 1
1m | R53 | R_1206_3216Metric | C7467246 | 1
1nF | C23,C50 | C_0402_1005Metric | C1523 | 2
1uF | C29,C35 | C_0402_1005Metric | C52923 | 2
2.2 | R37,R38,R39,R40 | R_0805_2012Metric | C17521 | 4
2.2uF | C54,C59,C61,C80 | C_0805_2012Metric | C377773 | 4
2.2uH | L1 | IND-SMD_L7.1-W6.6 | C497865 | 1
2.7nH | L4 | L_0201_0603Metric | C7216765 | 1
200 | R54,R63 | R_0402_1005Metric_Pad0.72x0.64mm_HandSolder | C25087 | 2
220k | R11,R13,R21,R23,R60 | R_0402_1005Metric | C25767 | 5
22k | R65 | R_0402_1005Metric | C25768 | 1
22uF | C13,C14,C66,C67,C82 | C_0805_2012Metric | C440198 | 5
2pF | C76,C85 | C_0201_0603Metric | C668326 | 2
3.3nF | C51 | C_0402_1005Metric | C26404 | 1
3.5nH | L5,L6 | L_0201_0603Metric | C3911055 | 2
300 | R27 | R_1206_3216Metric | C17887 | 1
30V | D1,D3 | D_SOT-23 | C22466368 | 2
32MHz | X1 | CRYSTAL-SMD_4P-L2.0-W1.6-BL-A | C37635332 | 1
330pF | C27,C28,C36,C81,C88 | C_0402_1005Metric | C13533 | 5
33nF | C31,C32 | C_0603_1608Metric | C21117 | 2
33pF | C39 | C_0402_1005Metric | C1562 | 1
390k | R20 | R_0603_1608Metric | C23150 | 1
4.7 | R3,R4 | R_0603_1608Metric | C23164 | 2
4.7k | R42,R43,R44,R58,R59,R62 | R_0402_1005Metric | C25900 | 6
4.7uF | C33,C62,C73,C78 | C_0402_1005Metric | C23733 | 4
4.7uH | L2,L3 | IND-SMD_L7.0-W6.6 | C5339435 | 2
40.2k | R14,R24 | R_0603_1608Metric | C12447 | 2
470nF | C34,C55,C86 | C_0603_1608Metric | C1623 | 3
47nF | C24,C25 | C_0603_1608Metric | C1622 | 2
5.1k | R33,R34,R36 | R_0402_1005Metric | C25905 | 3
5.6k | R57 | R_0402_1005Metric | C25908 | 1
680pF | C42 | C_0603_1608Metric | C1630 | 1
AT24C256C-SSHL-T | U6 | SOIC-8_L4.9-W3.9-P1.27-LS6.0-BL | C6482 | 1
BQ25713RSNR | U2 | RSN32_TEX | C2878935 | 1
BQ4050RSMR | U5 | VQFN-32_L4.0-W4.0-P0.40-TL-EP1.4 | C157570 | 1
H5VU25U | D2,D4,D5,D6 | DFN2510-10_L2.5-W1.0-P0.50-BL | C7420374 | 4
LED | D10,D11,D7,D8,D9 | LED_0603_1608Metric | C2290 | 5
Q_NMOS | Q1,Q2,Q4,Q5,Q7,Q8,Q9 | QNM30N20AJ-PDFN-8L_L3.3-W3.3-P0.65-BL_XINFEIHONG_FH1404G6 | C54300927 | 7
Q_PMOS | Q3,Q6 | ZC015P2G-POWERTDFN-8_L3.1-W3.1-P0.65-LS3.3-BL | C53433530 | 2
TPS25730DREFR | U1 | REF0038A-MFG | C22438973 | 1
TPS25762DQRQLRQ1 | U3 | RQL0029A-MFG | C43131301 | 1
USB_C_Receptacle_USB2.0_16P | J1,J2 | USB-C-SMD_TYPE-C16PIN | C18357551 | 2
nRF54L10-QFXX | U4 | QFN-48-1EP_6x6mm_P0.4mm_EP4.6x4.6mm_ThermalVias | C44800139 | 1
10k | TH1 | SolderWire-0.127sqmm_1x02_P3.7mm_D0.48mm_OD1mm |  | 1
SW_Push | SW2 | SolderWire-0.127sqmm_1x02_P3.7mm_D0.48mm_OD1mm |  | 1
SW_Push | SW3 | SW_PUSH_6mm |  | 1
SW_Push | SW1 | SW_PUSH_6mm |  | 1

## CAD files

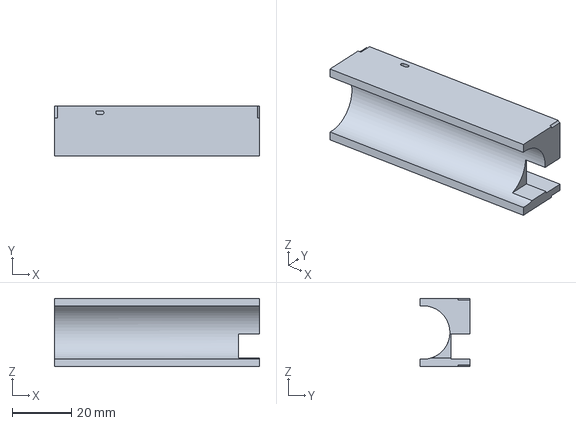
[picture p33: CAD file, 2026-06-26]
cad/components/Battery to PCB dock.step
69.0 x 16.8 x 23.0 mm

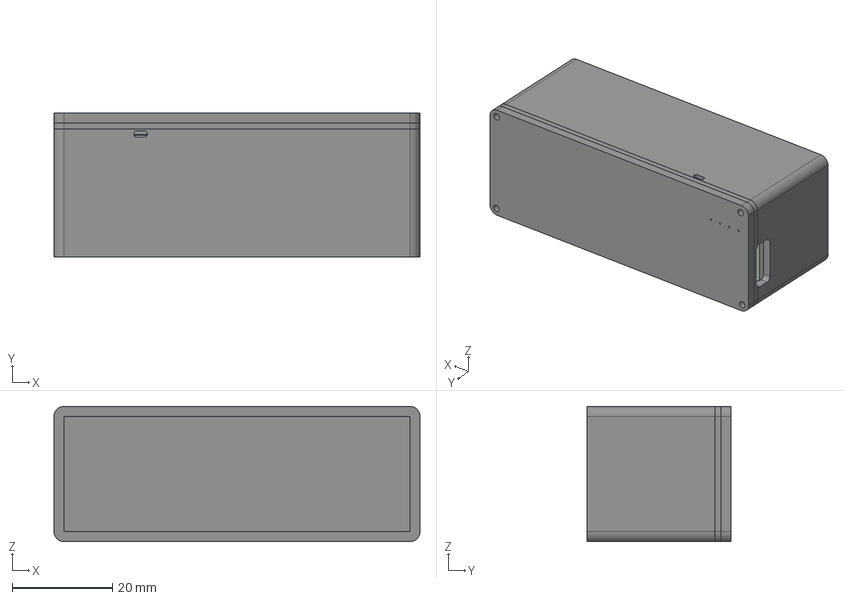
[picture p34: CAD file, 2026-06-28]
cad/FindMyCharger v2.step
73.0 x 28.8 x 27.0 mm
battery 186501^battery 18650(2)_battery 18650
battery 186502^battery 18650(2)_battery 18650
battery 186503^battery 18650(2)_battery 18650
battery 186504^battery 18650(2)_battery 18650
C_0402_1005Metric x 5
QFN-32_L5.0-W5.0-H1.0-P0.50-TL-EP3.5
R_0402_1005Metric x 3
C_0805_2012Metric x 7
KEY-TH_4P-L7.3-W4.5-H4.3-LS7.0-P5.0
R_0201_0603Metric
LED_0603_1608Metric x 4
IND-SMD_L6.0-W6.0_CHILISIN_HPPC06030
C_0603_1608Metric x 3
USB-C-SMD_TYPE-C16PIN
BULETM-SMD_E104-BT5005A
SOT-89-3_L4.3-W2.5-H1.6-LS4.1-P1.50
FindMyCharger_copper
FindMyCharger_pad
FindMyCharger_via
FindMyCharger_silkscreen
FindMyCharger_soldermask
FindMyCharger_soldermask_1
FindMyCharger_PCB

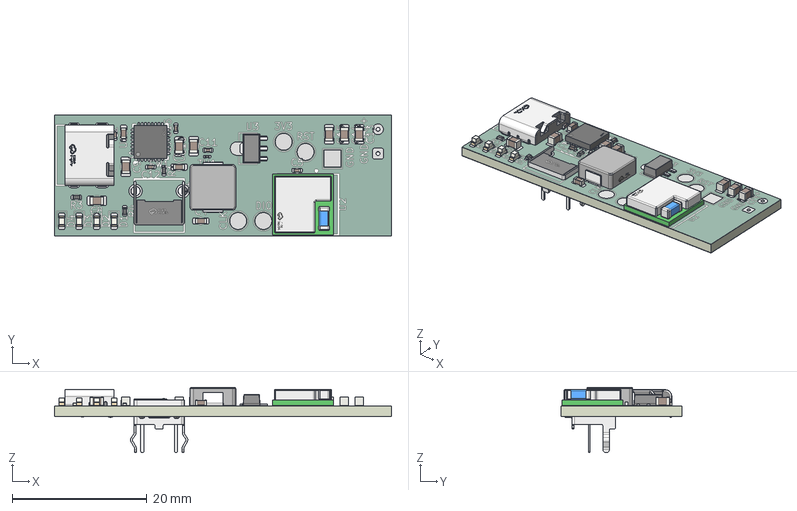
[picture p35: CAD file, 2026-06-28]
pcb/pcb.step
50.0 x 18.0 x 9.70 mm
C_0402_1005Metric x 5
QFN-32_L5.0-W5.0-H1.0-P0.50-TL-EP3.5
R_0402_1005Metric x 3
C_0805_2012Metric x 7
KEY-TH_4P-L7.3-W4.5-H4.3-LS7.0-P5.0
R_0201_0603Metric
LED_0603_1608Metric x 4
IND-SMD_L6.0-W6.0_CHILISIN_HPPC06030
C_0603_1608Metric x 3
USB-C-SMD_TYPE-C16PIN
BULETM-SMD_E104-BT5005A
SOT-89-3_L4.3-W2.5-H1.6-LS4.1-P1.50
FindMyCharger_copper
FindMyCharger_pad
FindMyCharger_via
FindMyCharger_silkscreen
FindMyCharger_soldermask x 2
FindMyCharger_PCB

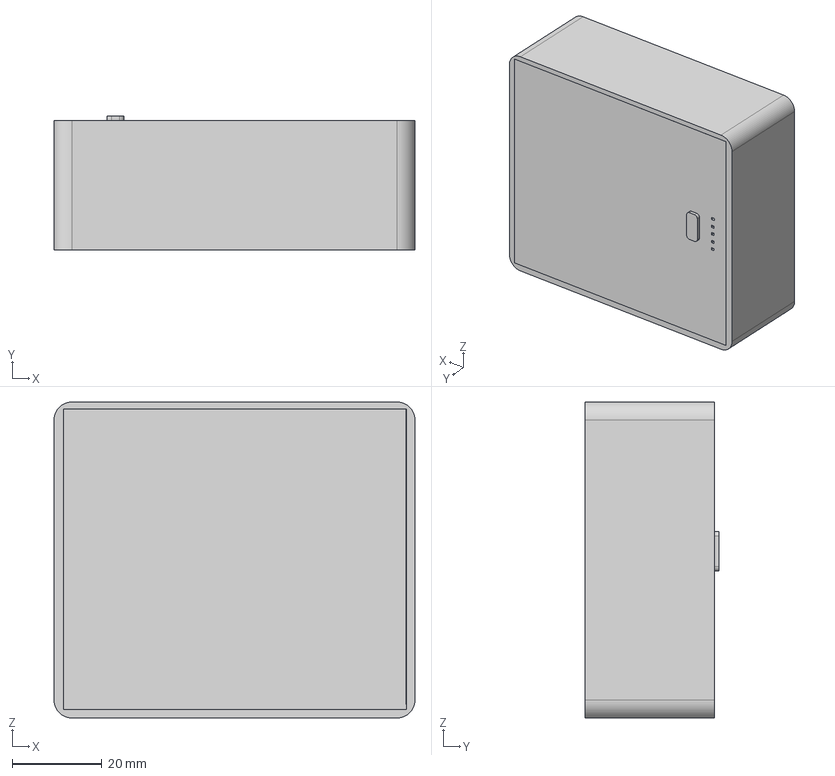
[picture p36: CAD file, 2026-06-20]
v1/cad/final.step
80.6 x 30.0 x 70.5 mm
battery 186501^battery 18650(2)_battery 18650 x 4
battery 186502^battery 18650(2)_battery 18650 x 4
battery 186503^battery 18650(2)_battery 18650 x 4
battery 186504^battery 18650(2)_battery 18650 x 4
C_0805_2012Metric x 24
LED_0603_1608Metric x 5
R_0402_1005Metric x 36
C_0603_1608Metric x 15
L_0201_0603Metric x 3
C_0402_1005Metric x 41
DFN2510-10_L2.5-W1.0-P0.50-BL x 4
C_0201_0603Metric x 5
R_0603_1608Metric x 9
R_0805_2012Metric x 13
L_0603_1608Metric
SW_PUSH_6mm x 2
R_1206_3216Metric x 5
IND-SMD_L6.6-W7.1-H3.0
D_SOT-23 x 2
FindMyCharger_PCB

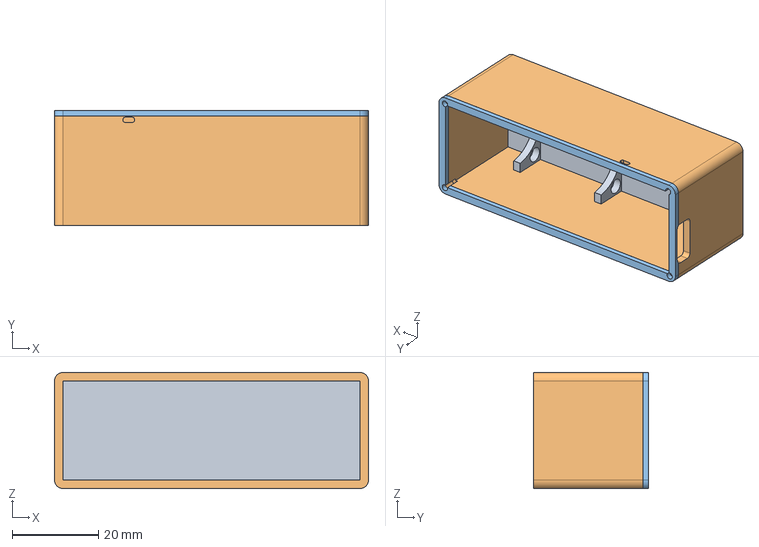
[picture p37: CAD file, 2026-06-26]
cad/components/Lower.step
73.0 x 26.8 x 27.0 mm

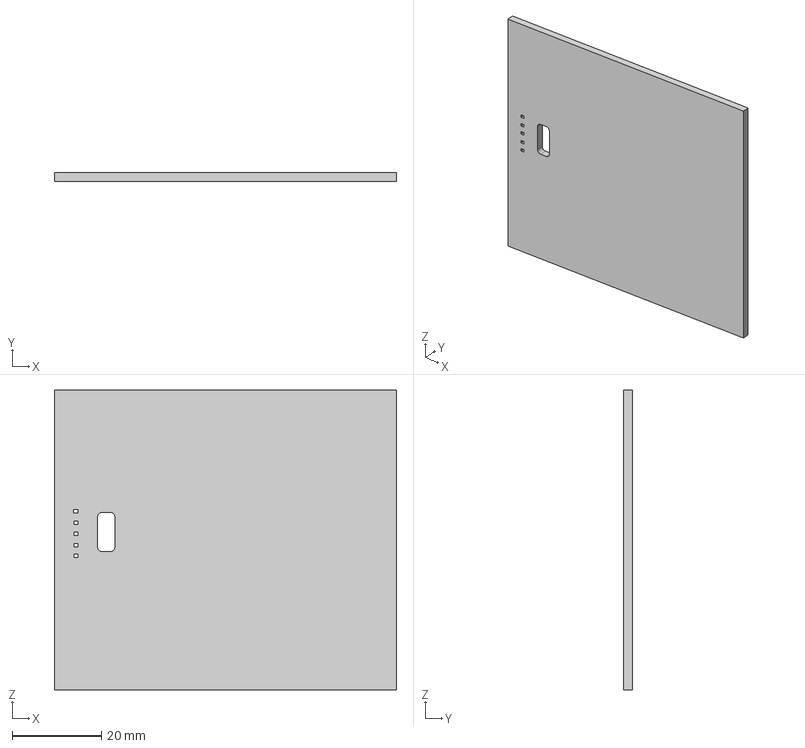
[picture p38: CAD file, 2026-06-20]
v1/cad/upper.step
76.6 x 2.00 x 67.1 mm

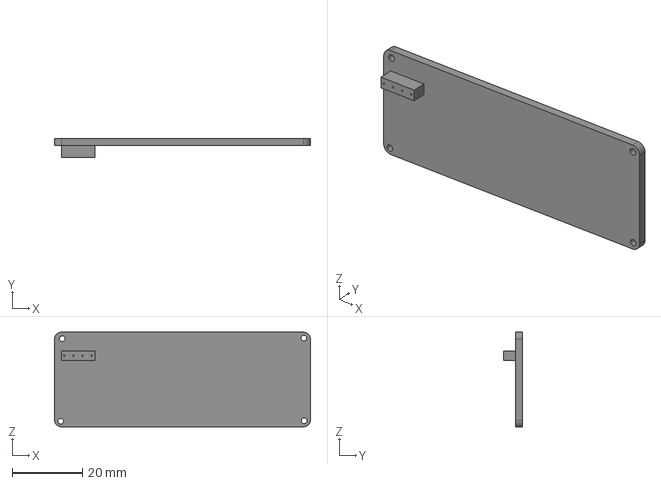
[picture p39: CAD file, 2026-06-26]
cad/components/Top.step
73.0 x 5.55 x 27.0 mm

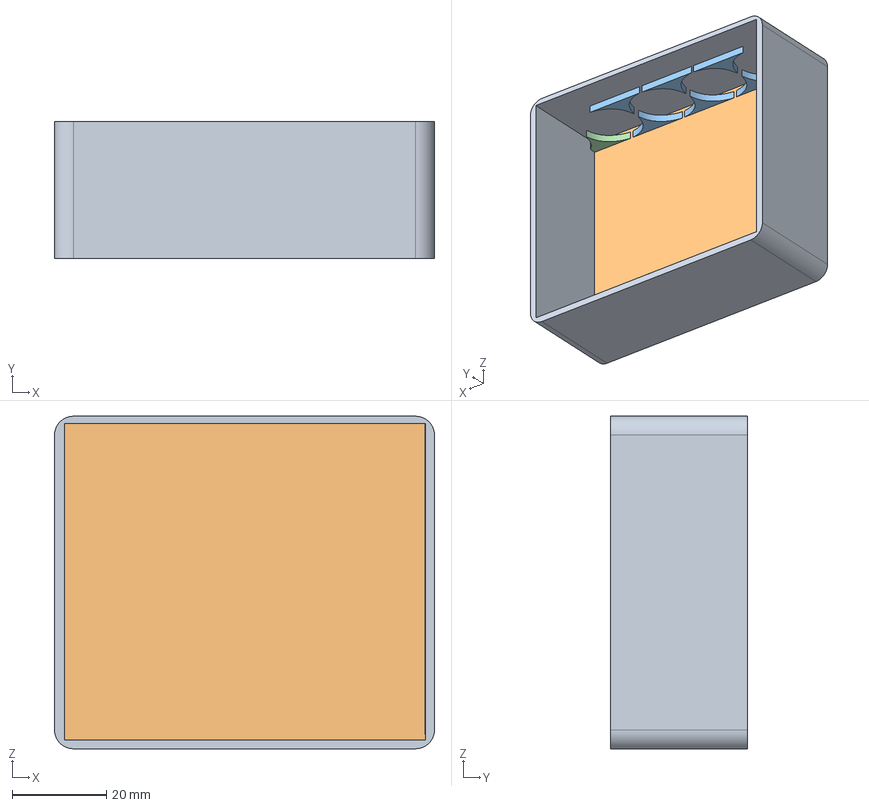
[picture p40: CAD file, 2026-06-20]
v1/cad/bottom.step
80.6 x 29.0 x 70.5 mm

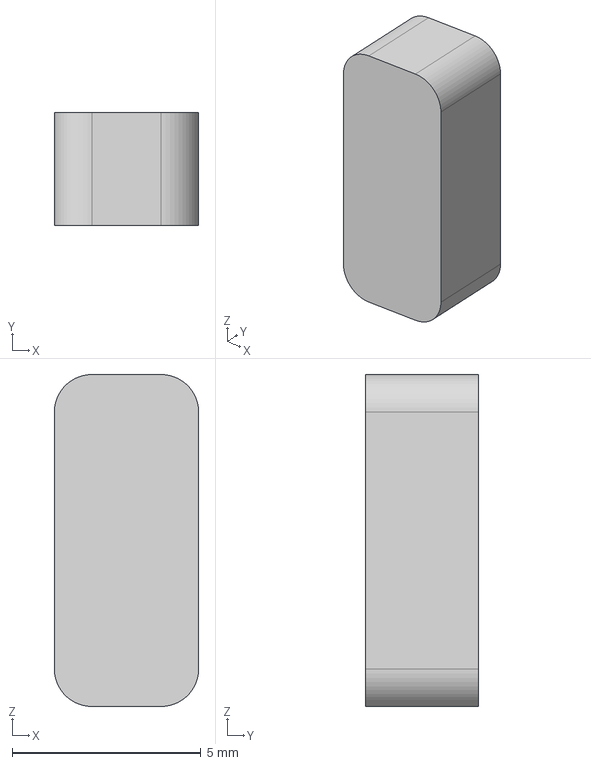
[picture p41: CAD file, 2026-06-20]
v1/cad/button.step
3.83 x 3.00 x 8.80 mm

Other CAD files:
v1/cad/findmycharger casing.f3z

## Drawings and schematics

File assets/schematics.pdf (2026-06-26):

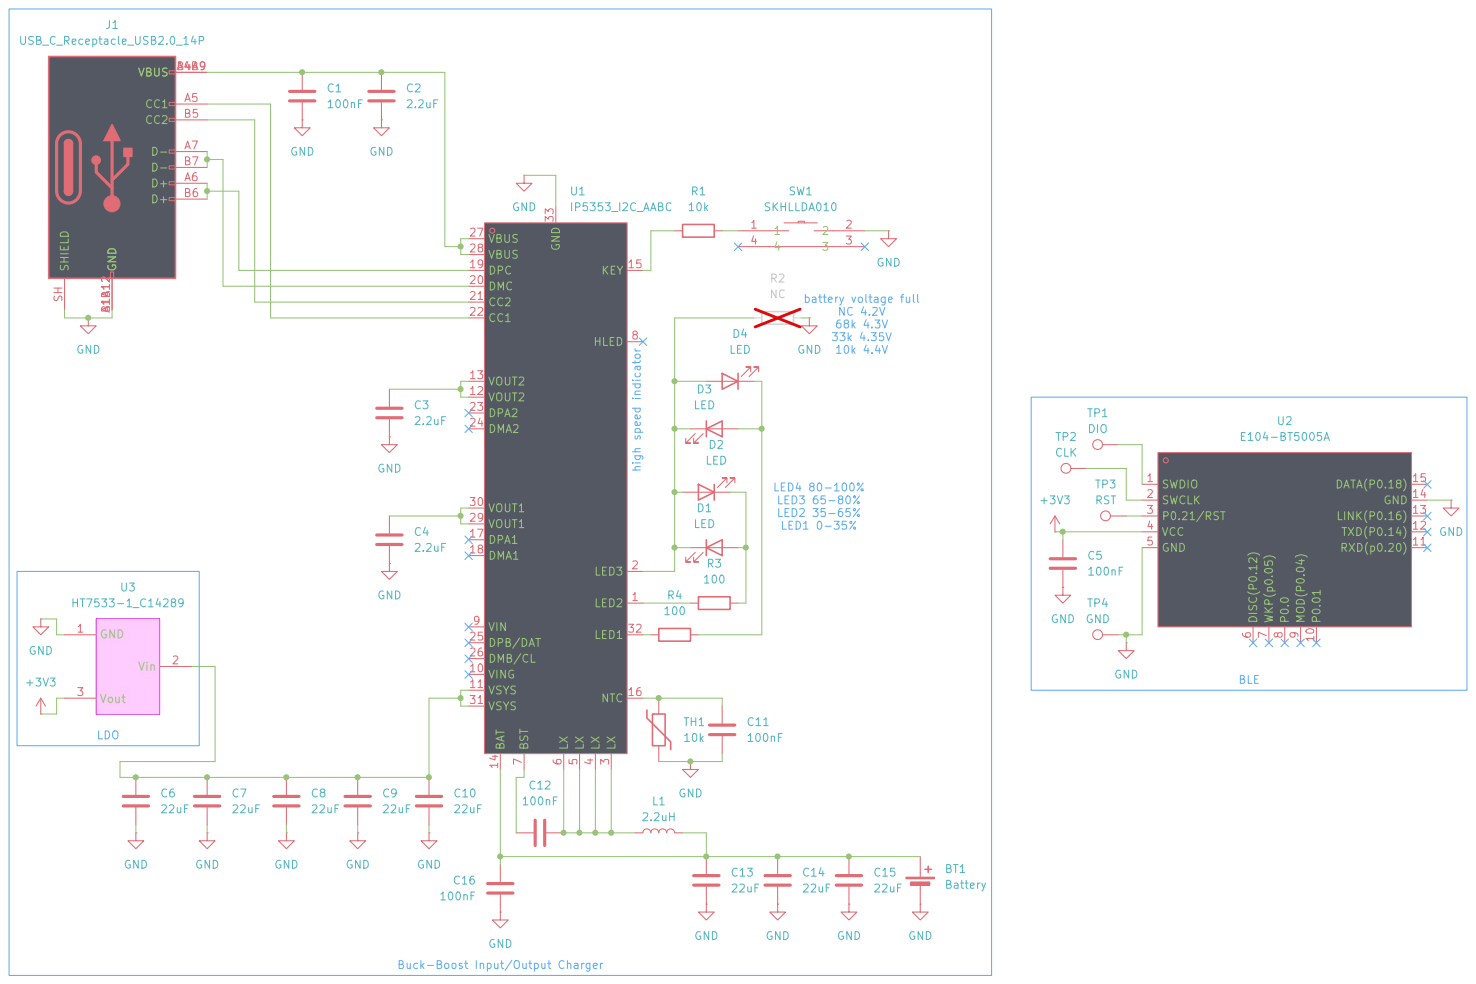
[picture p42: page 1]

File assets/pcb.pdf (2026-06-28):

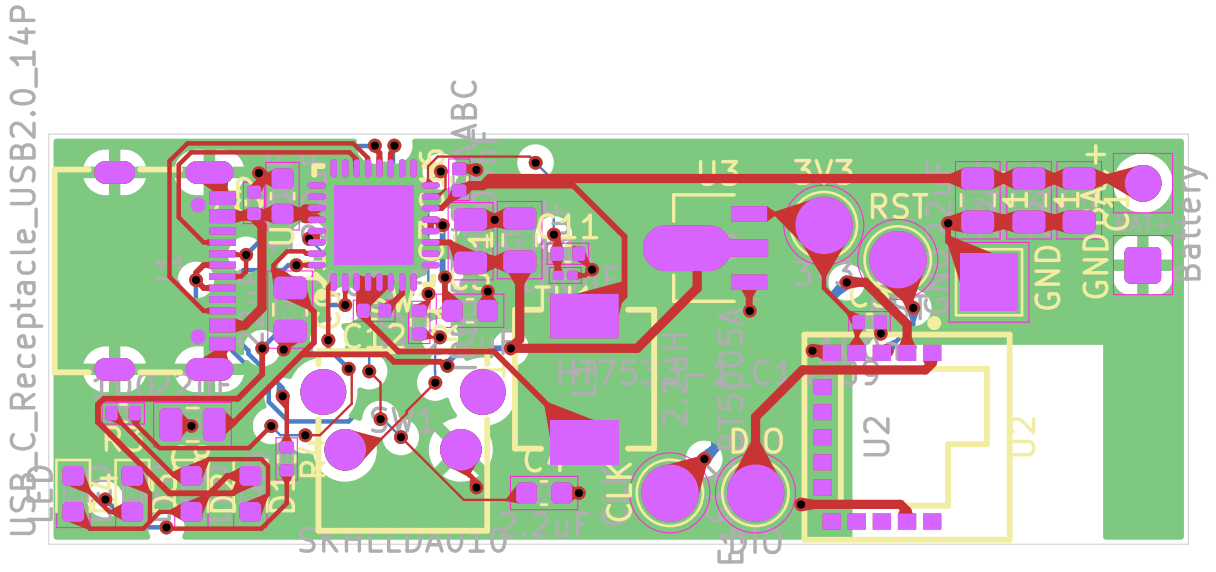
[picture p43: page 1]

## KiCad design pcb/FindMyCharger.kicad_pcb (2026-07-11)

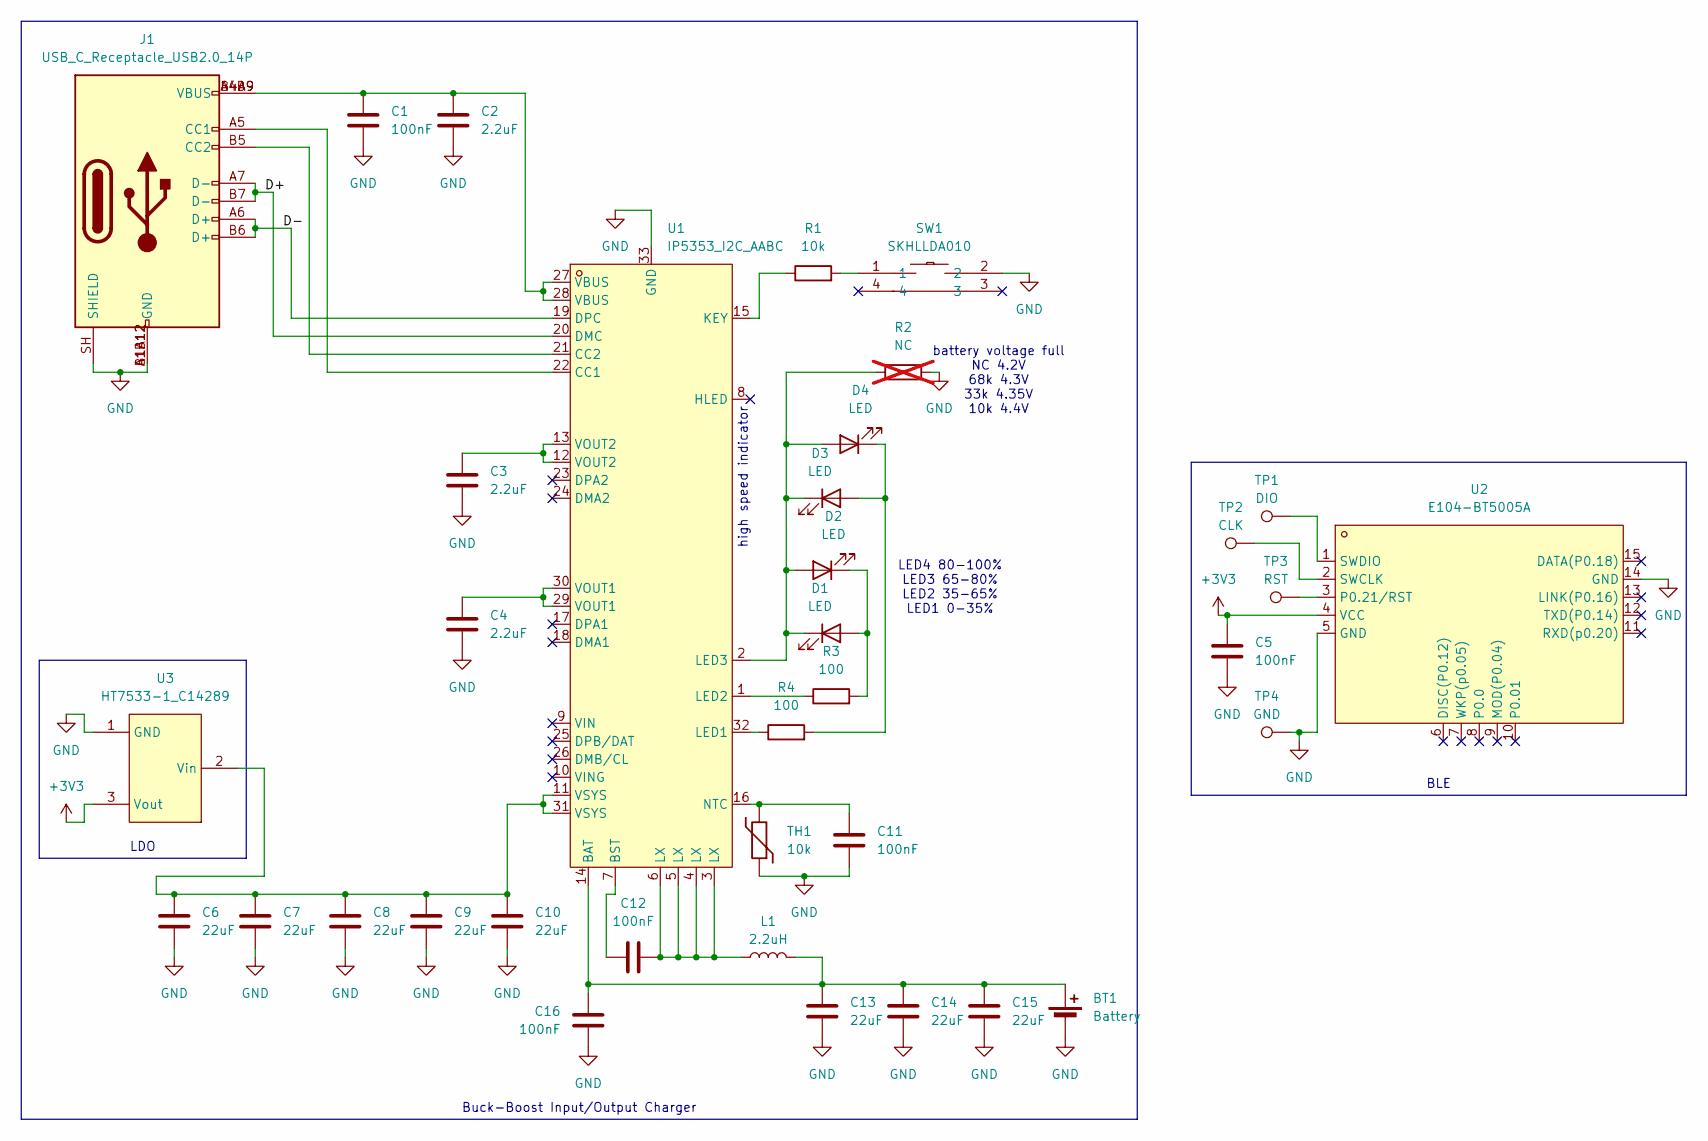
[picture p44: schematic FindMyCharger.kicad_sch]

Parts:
BT1: Battery; SolderWire-0.1sqmm_1x02_P3.6mm_D0.4mm_OD1mm
C1, C5, C11, C12, C16: 100nF; C_0402_1005Metric; LCSC Part C307331
C2, C3, C4: 2.2uF; C_0603_1608Metric; LCSC Part C23630
C6, C7, C8, C9, C10, C13, C14, C15: 22uF; C_0805_2012Metric; LCSC Part C45783
D1, D2, D3, D4: LED; LED_0603_1608Metric; LCSC Part C2290
J1: USB_C_Receptacle_USB2.0_14P; USB-C-SMD_TYPE-C16PIN; LCSC Part C393939
L1: 2.2uH; IND-SMD_L6.0-W6.0_CHILISIN_HPPC06030; LCSC Part C285900
R1: 10k; R_0402_1005Metric; LCSC Part C25744
R2: NC; R_0603_1608Metric; not fitted
R3, R4: 100; R_0402_1005Metric; LCSC Part C25076
SW1: SKHLLDA010; KEY-TH_SKHLLDA010; LCSC Part C125032
TH1: 10k; R_0402_1005Metric; LCSC Part C41417281
TP1: DIO; TestPoint_Pad_D2.5mm
TP2: CLK; TestPoint_Pad_D2.5mm
TP3: RST; TestPoint_Pad_D2.5mm
TP4: GND; TestPoint_Pad_2.5x2.5mm
U1: IP5353_I2C_AABC; QFN-32_L5.0-W5.0-P0.50-TL-EP3.5; LCSC Part C46550234
U2: E104-BT5005A; BULETM-SMD_E104-BT5005A; LCSC Part C2874127
U3: HT7533-1_C14289; SOT-89-3_L4.5-W2.5-P1.50-LS4.2-BR; LCSC Part C14289

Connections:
+3V3: C5.1, U2.4 (VCC), U3.3 (Vout); also elsewhere on the board
/D+: J1.A7 (D-), J1.B7 (D-), U1.20 (DMC)
/D-: J1.A6 (D+), J1.B6 (D+), U1.19 (DPC)
GND: BT1.1 (-), C1.2, C2.2, C3.2, C4.2, C5.2, C6.2, C7.2, C8.2, C9.2, C10.2, C11.2, C13.2, C14.2, C15.2, C16.2, J1.A1B12 (GND), J1.B1A12 (GND), J1.SH (SHIELD), R2.1, SW1.2, TH1.1, TP4.1 (1_1), U1.33 (GND), U2.5 (GND), U2.14 (GND), U3.1 (GND)
unnamed: BT1.2 (+), C13.1, C14.1, C15.1, C16.1, L1.2, U1.14 (BAT)
unnamed: C1.1, C2.1, J1.A4B9 (VBUS), J1.B4A9 (VBUS), U1.27 (VBUS), U1.28 (VBUS)
unnamed: C3.1, U1.12 (VOUT2), U1.13 (VOUT2)
unnamed: C4.1, U1.29 (VOUT1), U1.30 (VOUT1)
unnamed: C12.2, L1.1, U1.3 (LX), U1.4 (LX), U1.5 (LX), U1.6 (LX)
unnamed: D1.2 (A), D2.1 (K), R3.2
unnamed: D1.1 (K), D2.2 (A), D3.1 (K), D4.2 (A), R2.2, U1.2 (LED3)
unnamed: D3.2 (A), D4.1 (K), R4.2
unnamed: J1.A5 (CC1), U1.22 (CC1)
unnamed: J1.B5 (CC2), U1.21 (CC2)
unnamed: R1.2, SW1.1
unnamed: C12.1, U1.7 (BST)
unnamed: R1.1, U1.15 (KEY)
unnamed: R4.1, U1.32 (LED1)
unnamed: R3.1, U1.1 (LED2)
unnamed: C11.1, TH1.2, U1.16 (NTC)
unnamed 20: TP3.1, U2.3 (P0.21/RST); also elsewhere on the board
unnamed 21: TP2.1, U2.2 (SWCLK); also elsewhere on the board
unnamed 22: TP1.1, U2.1 (SWDIO); also elsewhere on the board
unnamed: C6.1, C7.1, C8.1, C9.1, C10.1, U1.11 (VSYS), U1.31 (VSYS), U3.2 (Vin)

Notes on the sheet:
high speed indicator
LED4 80-100% LED3 65-80% LED2 35-65% LED1 0-35%
battery voltage full NC 4.2V 68k 4.3V 33k 4.35V 10k 4.4V
BLE
LDO
Buck-Boost Input/Output Charger

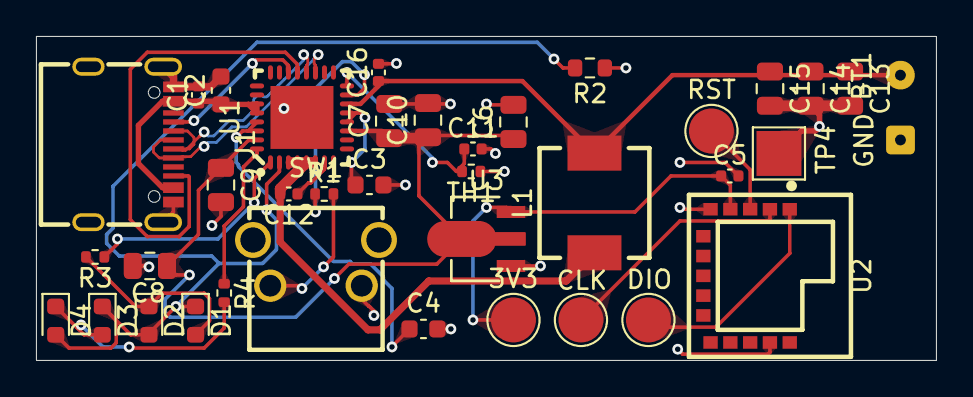
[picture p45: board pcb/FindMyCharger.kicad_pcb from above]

Board: 4 copper layers, 50.0 x 18.0 mm, 37 parts (0 on the bottom side), 24 nets.

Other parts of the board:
3V3: 3V3; TestPoint_Pad_D2.5mm
CLK: CLK; TestPoint_Pad_D2.5mm
DIO: DIO; TestPoint_Pad_D2.5mm
RST: RST; TestPoint_Pad_D2.5mm

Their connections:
+3V3: 3V3.1 (1_1); also elsewhere on the board
unnamed 20: RST.1 (1_1); also elsewhere on the board
unnamed 21: CLK.1 (1_1); also elsewhere on the board
unnamed 22: DIO.1 (1_1); also elsewhere on the board

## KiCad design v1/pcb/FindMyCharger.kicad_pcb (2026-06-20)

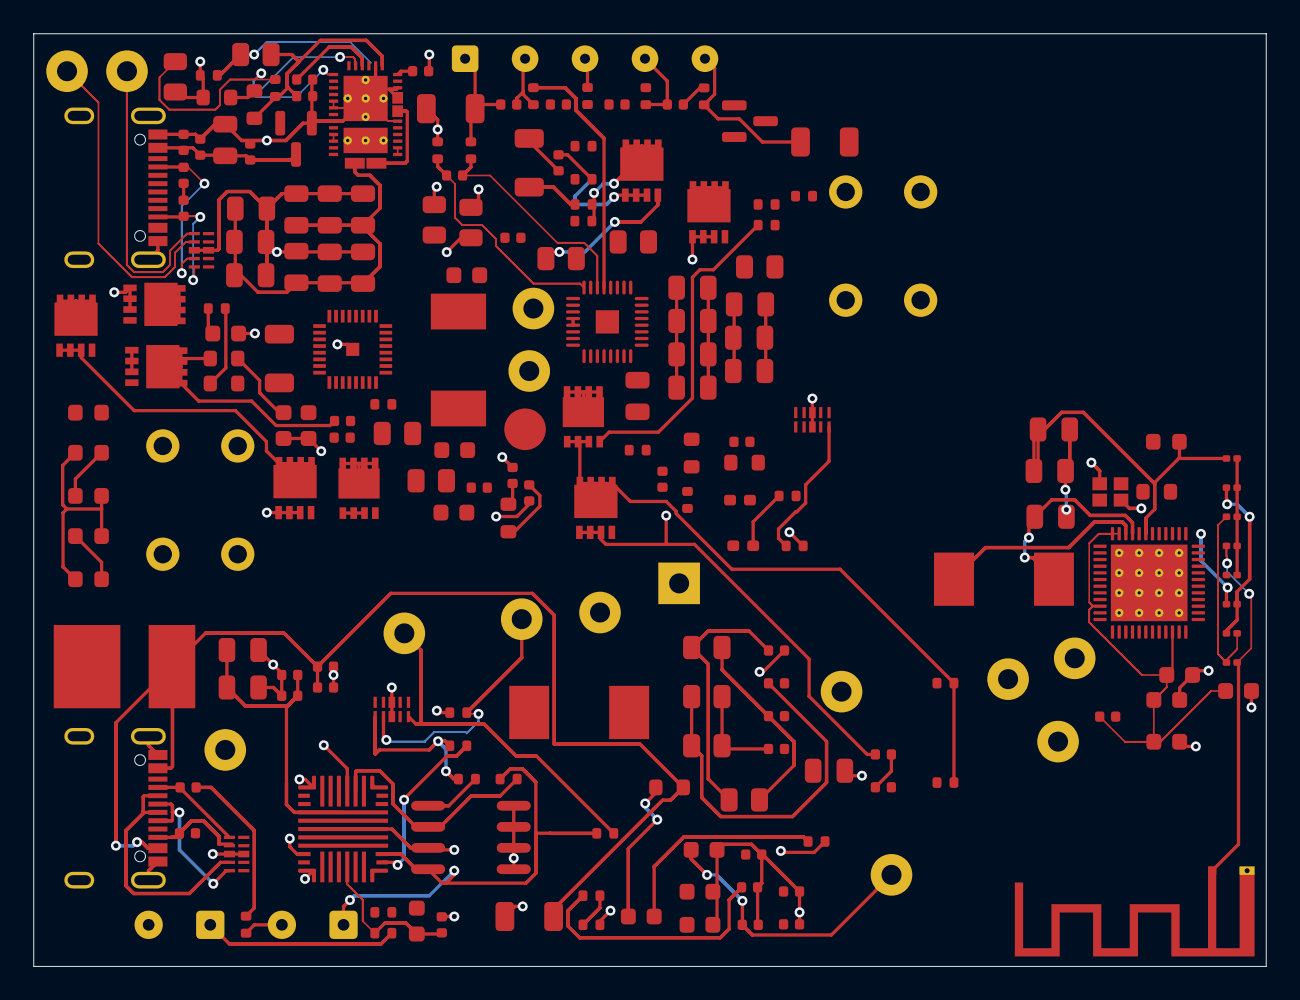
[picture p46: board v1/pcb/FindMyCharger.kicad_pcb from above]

Board: 4 copper layers, 74.0 x 56.0 mm, 206 parts (0 on the bottom side), 109 nets.

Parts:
AE1: Antenna; Texas_SWRA117D_2.4GHz_Right
C1, C30, C46: 10uF; C_0402_1005Metric
C2, C3, C11, C26, C37, C38, C48, C49, C52, C53, C56, C57, C58, C64, C65, C69, C70, C83, C84, C87: 0.1uF; C_0402_1005Metric
C4, C5, C6, C7, C8, C9, C10, C12, C15, C16, C17, C18, C19, C20, C21: 10uF; C_0805_2012Metric
C13, C14, C66, C67, C82: 22uF; C_0805_2012Metric
C22: 10nF; C_0402_1005Metric
C23, C50: 1nF; C_0402_1005Metric
C24, C25: 47nF; C_0603_1608Metric
C27, C28, C36, C81, C88: 330pF; C_0402_1005Metric
C29, C35: 1uF; C_0402_1005Metric
C31, C32: 33nF; C_0603_1608Metric
C33, C62, C73, C78: 4.7uF; C_0402_1005Metric
C34, C55, C86: 470nF; C_0603_1608Metric
C39: 33pF; C_0402_1005Metric
C40: 15pF; C_0402_1005Metric
C41: 1.8nF; C_0402_1005Metric
C42: 680pF; C_0603_1608Metric
C43, C44, C45, C47, C63, C74, C79: 100nF; C_0603_1608Metric
C51: 3.3nF; C_0402_1005Metric
C54, C59, C61, C80: 2.2uF; C_0805_2012Metric
C60: 10nF; C_0201_0603Metric
C68: 100uF; CAP-SMD_L7.3-W6.1_TCN4227M025R0100
C75: 1.5pF; C_0201_0603Metric
C76, C85: 2pF; C_0201_0603Metric
C77: 0.3pF; C_0201_0603Metric
D1, D3: 30V; D_SOT-23
D2, D4, D5, D6: H5VU25U; DFN2510-10_L2.5-W1.0-P0.50-BL
D7, D8, D9, D10, D11: LED; LED_0603_1608Metric
FB1: 120; L_0603_1608Metric
H1: cSDA; TestPoint_THTPad_D2.5mm_Drill1.2mm
H2: cSCL; TestPoint_THTPad_D2.5mm_Drill1.2mm
H4: oIRQ; TestPoint_THTPad_D2.5mm_Drill1.2mm
H5: oSCL; TestPoint_THTPad_D2.5mm_Drill1.2mm
H6: oSDA; TestPoint_THTPad_D2.5mm_Drill1.2mm
H7: 3V3; TestPoint_THTPad_D2.5mm_Drill1.2mm
H8: bSMBC; TestPoint_THTPad_D2.5mm_Drill1.2mm
H9: nRST; TestPoint_THTPad_D2.5mm_Drill1.2mm
H10: FUSE; TestPoint_Pad_D2.5mm
H11: eSCL; TestPoint_THTPad_D2.5mm_Drill1.2mm
H12: bSMBD; TestPoint_THTPad_D2.5mm_Drill1.2mm
H13: nSWDCLK; TestPoint_THTPad_D2.5mm_Drill1.2mm
H14: eSDA; TestPoint_THTPad_D2.5mm_Drill1.2mm
H15: GND; TestPoint_THTPad_2.5x2.5mm_Drill1.2mm
H16: nSWDIO; TestPoint_THTPad_D2.5mm_Drill1.2mm
J1, J2: USB_C_Receptacle_USB2.0_16P; USB-C-SMD_TYPE-C16PIN
J3: Battery_Connector; BMS_4S_PAD
L1: 2.2uH; IND-SMD_L7.1-W6.6
L2, L3: 4.7uH; IND-SMD_L7.0-W6.6
L4: 2.7nH; L_0201_0603Metric
L5, L6: 3.5nH; L_0201_0603Metric
Q1, Q2, Q4, Q5, Q7, Q8, Q9: Q_NMOS; QNM30N20AJ-PDFN-8L_L3.3-W3.3-P0.65-BL_XINFEIHONG_FH1404G6
Q3, Q6: Q_PMOS; ZC015P2G-POWERTDFN-8_L3.1-W3.1-P0.65-LS3.3-BL
R1, R2, R50: 10m; R_1206_3216Metric
R3, R4: 4.7; R_0603_1608Metric
R5: 1; R_0402_1005Metric
R6, R7, R17, R48, R61: 10; R_0402_1005Metric
R9, R15, R16, R18, R19, R25, R26, R30, R31: 10k; R_0805_2012Metric
R10: 160k; R_0603_1608Metric
R11, R13, R21, R23, R60: 220k; R_0402_1005Metric
R14, R24: 40.2k; R_0603_1608Metric
R20: 390k; R_0603_1608Metric
R22: 137k; R_0603_1608Metric
R27: 300; R_1206_3216Metric
R28, R29, R32: 10M; R_0402_1005Metric
R33, R34, R36: 5.1k; R_0402_1005Metric
R35, R41, R45, R47, R49, R51, R52, R55, R64: 100; R_0402_1005Metric
R37, R38, R39, R40: 2.2; R_0805_2012Metric
R42, R43, R44, R58, R59, R62: 4.7k; R_0402_1005Metric
R46: 0; R_0603_1608Metric
R53: 1m; R_1206_3216Metric
R54, R63: 200; R_0402_1005Metric_Pad0.72x0.64mm_HandSolder
R56: 1k; R_0603_1608Metric
R57: 5.6k; R_0402_1005Metric
R65: 22k; R_0402_1005Metric
SW1, SW3: SW_Push; SW_PUSH_6mm
SW2: SW_Push; SolderWire-0.127sqmm_1x02_P3.7mm_D0.48mm_OD1mm
TH1: 10k; SolderWire-0.127sqmm_1x02_P3.7mm_D0.48mm_OD1mm
U1: TPS25730DREFR; REF0038A-MFG
U2: BQ25713RSNR; RSN32_TEX
U3: TPS25762DQRQLRQ1; RQL0029A-MFG
U4: nRF54L10-QFXX; QFN-48-1EP_6x6mm_P0.4mm_EP4.6x4.6mm_ThermalVias
U5: BQ4050RSMR; VQFN-32_L4.0-W4.0-P0.40-TL-EP1.4
U6: AT24C256C-SSHL-T; SOIC-8_L4.9-W3.9-P1.27-LS6.0-BL
X1: 32MHz; CRYSTAL-SMD_4P-L2.0-W1.6-BL-A

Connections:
4P: C37.1, J3.BAT4, Q7.S, R27.1, R41.1
BMS_CHG: R33.2, U5.31 (CHG)
BMS_DSG: R36.1, U5.28 (DSG)
BMS_PACK: R30.2, U5.27 (PACK)
BMS_PCHG: R34.2, U5.30 (PCHG)
BMS_SMBC: R54.1, U5.19 (SMBC)
BMS_SMBD: R63.1, U5.18 (SMBD)
BMS_SRN: C58.1, C58.2, R51.1, R52.1, U5.6 (SRN), U5.8 (SRP)
BMS_VC1: R49.2, U5.5 (VC1)
BMS_VC2: R47.2, U5.4 (VC2)
BMS_VC3: R45.2, U5.3 (VC3)
BMS_VC4: C52.1, R41.2, U5.2 (VC4)
BMS_VCC: R35.1, U5.26 (VCC)
CC1_IN: C27.1, D2.4, J1.A5 (CC1), U1.28 (CC1)
CC1_OUT: C81.1, D5.1, J2.A5 (CC1), U3.20 (PA_CC1)
CC2_IN: C28.1, D2.5, J1.B5 (CC2), U1.29 (CC2)
CC2_OUT: C88.1, D5.2, J2.B5 (CC2), U3.19 (PA_CC2)
CHGND: C57.2, C80.1, J3.GND, R51.2, R53.1, U5.7 (NC), U5.9 (VSS), U5.23 (PTC), U5.24 (PTCEN)
CHG_SCL: D2.1, H2.1 (1_1), R18.1, U1.8 (I2Ct_SDA), U2.13 (SCL)
CHG_SDA: D2.2, H1.1 (1_1), R16.1, U1.9 (I2Ct_SCL), U2.12 (SDA)
DM_OUT: D5.4, J2.A7 (D-), J2.B7 (D-), U3.17 (PA_DM_GPIO7)
DP_OUT: D5.5, J2.A6 (D+), J2.B6 (D+), U3.18 (PA_DP_GPIO8)
GND: C1.2, C2.2, C3.2, C4.2, C5.2, C6.2, C7.2, C8.2, C9.2, C10.2, C11.2, C12.2, C13.2, C14.2, C15.2, C16.2, C17.2, C18.2, C19.2, C20.2, C21.2, C22.2, C23.2, C27.2, C28.2, C30.2, C31.2, C32.2, C33.2, C34.2, C39.1, C41.2, C43.2, C44.2, C45.2, C46.2, C47.2, C62.2, C63.2, C64.2, C65.2, C66.2, C67.2, C68.2, C69.2, C70.2, C73.2, C74.2, C78.2, C79.2, C82.2, C83.2, C84.2, C87.2, C88.2, D1.1, D2.3, D2.8, D4.3, D4.8, D5.3, D5.8, D6.3, D6.8, H15.1 (1_1), J1.A1B12 (GND), J1.B1A12 (GND), J1.SH (SHIELD), J2.A1B12 (GND), J2.B1A12 (GND), J2.SH (SHIELD), Q4.S, Q5.S, R13.2, R14.2, R15.2, R52.2, R53.2, R65.2, SW2.2, U1.2 (ADCIN1), U1.11 (GND), U1.12 (GND), U1.14 (GND), U1.16 (GND), U1.17 (GND), U1.26 (Reserved), U1.27 (Reserved), U1.31 (GND), U1.34 (GND), U1.35 (GND), U1.36 (Reserved), U1.39 (GND_PAD), U2.14 (CMPIN), U2.27 (PGND), U2.HTAB (EPAD), U3.5 (AGND), U3.13 (PGND), U4.32 (VSS_PA), U4.44 (VSS), U4.49 (VSS), U5.10 (TS1), U5.11 (TS2), U5.12 (TS3), U5.13 (TS4), U5.14 (NC), U5.33 (EPAD), U6.1 (A0), U6.2 (A1), U6.3 (A2), U6.4 (GND), U6.7 (WP), X1.2 (GND), X1.4 (GND)
INPUT_ACN: C32.1, R4.2, U2.2 (ACN)
INPUT_ACP: C31.1, R3.2, U2.3 (ACP)
INPUT_BATDRV: Q3.G, U2.21 (*BATDRV)
INPUT_BTST1: C24.2, U2.30 (BTST1)
INPUT_BTST2: C25.2, U2.25 (BTST2)
INPUT_CELL_BATPRESZ: R19.2, U2.18 (CELL_BATPRESZ)
INPUT_HIDRV1: Q1.G, U2.31 (HIDRV1)
INPUT_HIDRV2: Q2.G, U2.24 (HIDRV2)
INPUT_LODRV1: Q4.G, U2.29 (LODRV1)
INPUT_LODRV2: Q5.G, U2.26 (LODRV2)
INPUT_PWR: C13.1, C14.1, C15.1, C16.1, C17.1, C18.1, C19.1, C20.1, C21.1, R1.1, R3.1, R5.2, U1.20 (PPHV), U1.21 (PPHV), U1.22 (PPHV)
INPUT_SRN: R7.1, U2.19 (SRN)
INPUT_SRP: R6.1, U2.20 (SRP)
INPUT_SW1: C24.1, Q1.S, Q4.D, U2.32 (SW1)
INPUT_SW2: C25.1, Q2.S, Q5.D, U2.23 (SW2)
INPUT_VBUS: C34.1, R5.1, U2.1 (VBUS)
INPUT_VDDA: R19.1, U2.7 (VDDA)
INPUT_VSYS: C4.1, C5.1, C6.1, C7.1, C8.1, C9.1, C10.1, C82.1, C83.1, C84.1, Q2.D, Q3.S, R60.1, U2.22 (VSYS), U3.15 (IN)
unnamed: AE1.1 (A_1), C77.1, L6.2
unnamed: C22.1, C23.1, Q1.D, R1.2, R4.1
unnamed: C26.1, C29.1, Q3.D, R2.2, R6.2
unnamed: C37.2, C38.1
unnamed: C41.1, R24.2
unnamed: C50.1, R37.2, R38.2
unnamed: C51.1, R39.2, R40.2
unnamed: C75.1, L4.2, L5.1
unnamed: C76.1, L5.2, L6.1
unnamed: C86.2, R61.1
unnamed: D6.4, R63.2, R64.1
unnamed: D6.5, R54.2, R55.1
unnamed: D7.2 (A), D8.1 (K), U5.22 (LEDCNTLC)
unnamed: D7.1 (K), D8.2 (A), D10.2 (A), D11.1 (K), U5.21 (LEDCNTLB)
unnamed: D10.1 (K), D11.2 (A), U5.20 (LEDCNTLA)
unnamed: H8.1 (1_1), R55.2
unnamed: H12.1 (1_1), R64.2
unnamed: C57.1, J3.BAT1, R49.1
unnamed: C52.2, J3.BAT3, R45.1
unnamed: J3.BAT2 (Pin_2), R47.1
unnamed: Q6.G, R32.1, R34.1
unnamed: Q6.S, Q7.D, Q8.D, R32.2, R35.2
unnamed: Q7.G, R33.1
unnamed: Q8.G, Q9.D, R28.2, R36.2
unnamed: Q9.G, R31.1
unnamed: R57.2, SW2.1
unnamed: U1.15 (DRAIN), U1.30 (DRAIN), U1.40 (DRAIN_PAD)
unnamed: C33.1, U1.4 (LDO_1V5)
unnamed: C1.1, U1.38 (VIN_3V3)
unnamed: C39.2, R24.1, U2.16 (COMP1)
unnamed: R26.1, U2.17 (COMP2)
unnamed: D4.5, H4.1 (1_1), R44.2, U3.24 (GPIO1_IRQ2(o))
unnamed: D4.2, H6.1 (1_1), R42.2, U3.25 (GPIO2_I2C_SCL2)
unnamed: D4.4, H5.1 (1_1), R43.2, U3.26 (GPIO3_I2C_SDA2)
unnamed: C78.1, C79.1, U3.7 (LDO_1V5)
unnamed: C73.1, C74.1, U3.21 (LDO_5V)
unnamed: L4.1, U4.31 (ANT)
unnamed: L3.1, U4.46 (DCC)
unnamed: C59.1, C60.1, C61.1, FB1.2, U4.33 (DECRF), U4.43 (DECA)
unnamed: C54.1, FB1.1, L3.2, U4.45 (DECD)
unnamed: D6.1, H13.1 (1_1), U4.26 (SWDCLK)
unnamed: D6.2, H16.1 (1_1), U4.25 (SWDIO)
unnamed: U4.34 (XC1), X1.1
unnamed: U4.35 (XC2), X1.3
unnamed: C85.1, R56.1, U4.30 (~RESET)
unnamed: H10.1 (1_1), U5.25 (FUSE)
unnamed: C80.2, U5.1 (PBI)
OUTPUT_BOOT1: C48.2, U3.16 (BOOT1)
OUTPUT_BOOT2: C49.2, U3.10 (BOOT2)
OUTPUT_CSN_BUS: C55.1, R46.1, U3.29 (CSN_BUS)
OUTPUT_CSP: C55.2, R48.1, U3.28 (CSP)
OUTPUT_EN_UVLO: R60.2, R65.1, U3.6 (EN_UVLO)
OUTPUT_LDO_3V3: C43.1, C44.1, C45.1, C46.1, C47.1, C62.1, C63.1, D4.1, H7.1 (1_1), R16.2, R18.2, R42.1, R43.1, R44.1, R58.1, R59.1, TH1.1, U3.27 (LDO_3V3), U4.10 (VDD), U4.22 (VDD), U4.36 (VDD), U4.47 (VDD), U4.48 (VDD), U6.8 (VCC)
OUTPUT_NTC: R62.1, TH1.2, U3.8 (GPIO5_NTC)
OUTPUT_OUT: C64.1, C65.1, C66.1, C67.1, R48.2, R50.1, U3.11 (OUT)
OUTPUT_SCL1: H11.1 (1_1), R58.2, U3.3 (I2C_SCL1), U6.6 (SCL)
OUTPUT_SDA1: H14.1 (1_1), R59.2, U3.4 (I2C_SDA1), U6.5 (SDA)
OUTPUT_SW1: C48.1, R37.1, R38.1, U3.14 (SW1)
OUTPUT_SW2: C49.1, R39.1, R40.1, U3.12 (SW2)
OUTPUT_TVSP: C86.1, C87.1, R57.1, U3.22 (TVSP)
PACK+: C26.2, C38.2, Q8.S, Q9.S, R2.1, R7.2, R28.1, R30.1
PD_ADCIN1: C29.2, C50.2, C51.2, C54.2, C59.2, C60.2, C61.2, C75.2, C76.2, C77.2, C81.2, C85.2, R31.2, R61.2, R62.2
PD_ADCIN2: R9.2, R13.1, U1.3 (ADCIN2)
PD_ADCIN3: R10.2, R14.1, U1.5 (ADCIN3)
PD_ADCIN4: R11.2, R15.1, U1.7 (ADCIN4)
PD_LDO_3V3: C30.1, R9.1, R10.1, R11.1, U1.1 (LDO_3V3)
VBUS_IN: C2.1, C3.1, C11.1, C12.1, D1.3, J1.A4B9 (VBUS), J1.B4A9 (VBUS), U1.23 (VBUS_IN), U1.24 (VBUS_IN), U1.25 (VBUS_IN), U1.32 (VBUS), U1.33 (VBUS)
VBUS_OUT: C68.1, C69.1, C70.1, J2.A4B9 (VBUS), J2.B4A9 (VBUS), R46.2, R50.2

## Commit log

2025-11-24 KiCad files init
    [FindMyCharger.kicad_pcb, FindMyCharger.kicad_sch]
2025-11-24 Added nRF54 IC onto schematics
    [FindMyCharger.kicad_sch]
2025-11-25 Included footprint
    [FindMyCharger.kicad_sch]
2025-12-01 clean .gitignore and included buck boost
    [FindMyCharger.kicad_pcb, FindMyCharger.kicad_sch]
2025-12-01 started to connect batteries
    [FindMyCharger.kicad_sch]
2025-12-02 starting to connect cells to BMS
    [FindMyCharger.kicad_sch]
2025-12-02 moved a bit into the paper
    [FindMyCharger.kicad_sch]
2025-12-05 vault backup: 2025-12-05 22:39:07
    [FindMyCharger.kicad_sch]
2025-12-06 finished making the battery pack schematics :)
    [FindMyCharger.kicad_sch]
2025-12-11 added usb c connector
    [FindMyCharger.kicad_sch]
2025-12-12 replace bms
    [FindMyCharger.kicad_sch]
2025-12-12 replaced bms
    [FindMyCharger.kicad_sch]
2025-12-12 connected moisture detection
    [FindMyCharger.kicad_sch]
2025-12-15 is it just me or I can't just make my mind up
    [FindMyCharger.kicad_sch]
2025-12-27 Updated libraries
    [FindMyCharger.kicad_sch]
2025-12-27 Connected quite some stuff, still a long way to go
    [FindMyCharger.kicad_sch]
2025-12-28 Finished input charge
    [FindMyCharger.kicad_sch]
2025-12-28 Updated README and connected more stuff
    [FindMyCharger.kicad_sch]
2025-12-28 more stuff
    [FindMyCharger.kicad_sch]
2025-12-30 protection IC
    [FindMyCharger.kicad_sch]
2025-12-30 Finished BMS
    [FindMyCharger.kicad_sch]
2025-12-30 Finished BMS handling, kinda
    [FindMyCharger.kicad_sch]
2025-12-31 Finished circuit
    [FindMyCharger.kicad_sch]
2026-01-01 left to include test pads for comms
    [FindMyCharger.kicad_sch]
2026-01-22 updating to tps25772-q1 from *762* to "save" space
    [FindMyCharger.kicad_sch]
2026-01-23 more i2c
    [FindMyCharger.kicad_sch]
2026-01-23 remove old charging, gotta setup new one
    [FindMyCharger.kicad_sch]
2026-01-24 more filling
    [FindMyCharger.kicad_sch]
2026-01-25 schematics done
    [FindMyCharger.kicad_sch]
2026-01-25 returning to 762 bc 772 only supports as source, not sink
    [FindMyCharger.kicad_sch]
2026-01-25 added capacitors and inductors as per nrf54 datasheet
    [FindMyCharger.kicad_sch]
2026-01-25 including some footprints
    [FindMyCharger.kicad_sch]
2026-02-01 connected antenna footprint
    [FindMyCharger.kicad_sch]
2026-03-24 some footprints assigment (incomplete)
    [FindMyCharger.kicad_sch]
2026-03-26 to do list update + capacitor footprints assigned
    [FindMyCharger.kicad_sch]
2026-03-27 update goals and todos
    [FindMyCharger.kicad_sch]
2026-03-27 include volts
    [FindMyCharger.kicad_sch]
2026-04-02 kicad 10 update + some power rating
    [FindMyCharger.kicad_sch]
2026-04-03 more pads n update todo
    [FindMyCharger.kicad_sch]
2026-04-19 some esd
    [FindMyCharger.kicad_sch]
2026-04-19 more esd + research
    [FindMyCharger.kicad_sch]
2026-04-19 shield to gnd
    [FindMyCharger.kicad_sch]
2026-05-29 replace with non handsolder
    [FindMyCharger.kicad_sch]
2026-05-29 add 2010
    [FindMyCharger.kicad_sch]
2026-05-30 fix SNS power rating
    [FindMyCharger.kicad_sch]
2026-05-30 some stuf
    [FindMyCharger.kicad_sch]
2026-05-31 no handsolder
    [FindMyCharger.kicad_sch]
2026-06-07 return footprint
    [FindMyCharger.kicad_sch]
2026-06-08 update nrf54 footprints
    [FindMyCharger.kicad_sch]
2026-06-08 hide property
    [FindMyCharger.kicad_sch]
2026-06-08 config stuf
    [FindMyCharger.kicad_sch]
2026-06-10 add drc pcb jlcpcb
    [FindMyCharger.kicad_pcb, FindMyCharger.kicad_sch]
2026-06-10 datasheet and sch changes
    [FindMyCharger.kicad_sch]
2026-06-11 rm handsolder
    [FindMyCharger.kicad_sch]
2026-06-11 fixed metric
    [FindMyCharger.kicad_sch]
2026-06-11 fix metric removed bc of backup
    [FindMyCharger.kicad_sch]
2026-06-12 update visibility
    [FindMyCharger.kicad_sch]
2026-06-16 update naming
    [FindMyCharger.kicad_sch]
2026-06-18 tidy up
    [FindMyCharger.kicad_sch]
2026-06-20 more part
    [FindMyCharger.kicad_sch]
2026-06-20 updated footprint
    [FindMyCharger.kicad_sch]
2026-06-20 excl debug/pads from bom
    [FindMyCharger.kicad_pcb, FindMyCharger.kicad_sch]
2026-06-20 finished mapping
    [FindMyCharger.kicad_pcb, FindMyCharger.kicad_sch]
2026-06-20 firmware init
    [FindMyCharger.kicad_pcb]
2026-06-20 fixed bracket
2026-06-21 main cad
    [findmycharger casing.f3z]
2026-06-23 add ble
    [FindMyCharger.kicad_sch]
2026-06-25 footprint assignemnt done
    [FindMyCharger.kicad_sch]
2026-06-26 fix 3dmodels mapping
    [.step, FindMyCharger.kicad_pcb]
2026-06-26 updated bom
2026-06-27 fix via directly on component
    [BOM-FindMyCharger.csv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]
2026-06-27 forgot to connect nRST
    [CPL-FindMyCharger.csv, FindMyCharger-CuBottom.gbr, FindMyCharger-CuIn1.gbr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]
2026-06-28 fixed drc
    [CPL-FindMyCharger.csv, FindMyCharger-CuBottom.gbr, FindMyCharger-CuIn1.gbr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]
2026-06-28 updated docs, fixed naming
    [FindMyCharger 2 Casing.step, FindMyCharger v2.step, FindMyCharger.kicad_pcb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]
2026-06-28 add footprints list
2026-06-28 updated bom url
2026-07-11 made differential pair with impedance config from jlcpcb's calculator for usb
    [BOM-FindMyCharger.csv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]
2026-07-11 fixed differential pair track
    [BOM-FindMyCharger.csv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]
2026-07-11 added curve
    [FindMyCharger-CuBottom.gbr, FindMyCharger-CuIn1.gbr, FindMyCharger-CuIn2.gbr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]
2026-07-11 fixed testpad silkscreen
    [FindMyCharger-CuBottom.gbr, FindMyCharger-CuIn1.gbr, FindMyCharger-CuIn2.gbr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]
